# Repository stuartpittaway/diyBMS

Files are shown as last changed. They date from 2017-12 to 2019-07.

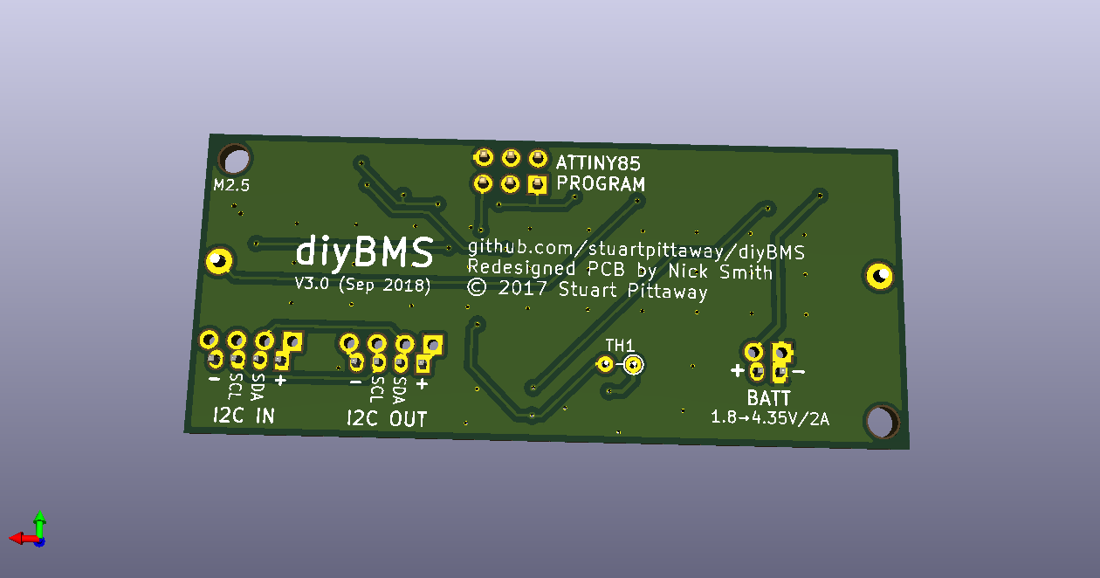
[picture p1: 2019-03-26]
BMS-Cell-Module-Circuit/PCB-back.png

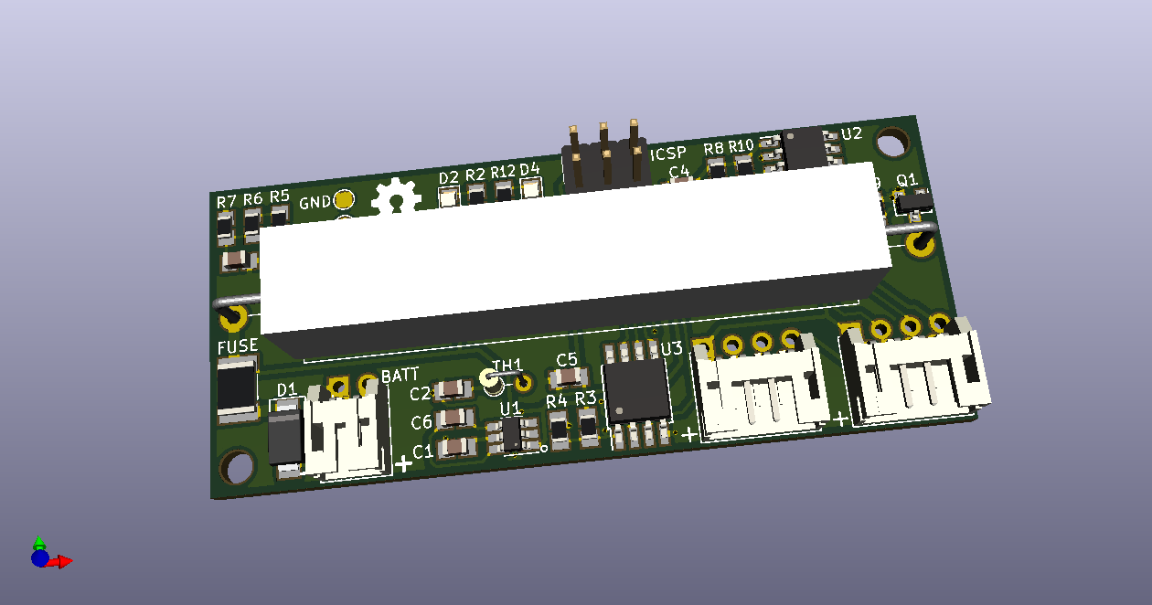
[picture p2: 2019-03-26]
BMS-Cell-Module-Circuit/PCB-3D.png

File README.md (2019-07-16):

# diyBMS
Do it yourself battery management system to Lithium ion battery packs/cells

More discussion
https://community.openenergymonitor.org/t/diy-lithium-battery-balancer-and-monitoring-bms/5594/10

** PLEASE NOTE THIS DESIGN HAS BEEN REPLACED WITH VERSION 4 **

https://github.com/stuartpittaway/diyBMSv4

# YouTube

https://www.youtube.com/watch?v=-CusvENqC4I&t=12s

Some Youtube videos on the BMS building and testing can be found at
https://www.youtube.com/playlist?list=PLiYbY8lzAN-2qB9rR0Sc7Z7sUrsgYzsiV

# Problem

A DIY Powerwall is the DIY construction of a pack of battery cells to create an energy store which can be used via inverters to power electrical items in the home. Generally cells are salvaged/second hand, and typically use Lithium 18650 cells.

Lithium batteries need to be kept at the same voltage level across a parallel pack. This is done by balancing each cell in the pack to raise or lower its voltage to match the others.

Existing balancing solutions are available in the market place, but at a relatively high cost compared to the cost of the battery bank, so this project is to design a low-cost, simple featured BMS/balancer.

A large number of people have utilised the commercial BATRIUM BMS system in their powerwall devices.

# My Situtation/Environment

UK based, but with only a small setup.  I have a 7s96p setup which i need to keep in balance.

# Existing Energy Usage

Through the monitoring of my home electric usage using the emonTX and emonSD solutions I typically use around 9kW/H per day (excluding electric car charging). Apart from odd spikes, load it generally less than 500W for the majority of the day/night.

# The Plan

Install a DIY powerwall with the ability to supply a 1000W load to cover all regular home usage (excluding spikes which the grid will handle).

A grid tied inverter would be required to convert the battery DC into mains level AC.

A controllable charger would be required to charge the battery during the day (or at cheap energy times from the grid). Ideally the charger should be able to match the generation of export from the solar array(s) to prevent import.

It may be possible to combine both charger and inverter into a single unit (so called hybrid units)

For obvious reasons, safety is critical, so care must be taken to ensure components are installed and certified as needed, along with the correct specification for cables, breakers and fuses etc.

Why am I doing this? For fun :slight_smile: I really must get out more!

# WARNING

Just a reminder that this is a DIY product/solution so don’t use this for safety critical systems or in any situation where there could be a risk to life.  There is no warranty, it may not work as expected or at all.

# Parameters

I’m working to the the following design parameters, which are taken from research into the area (what most others are doing!)

Assumption that second hand 18650 cells are made into “packs” containing tens or hundreds of cells in parallel.
Voltage of 18650 cell between 3.0V (empty) and 4.2V (full)
48V DC battery pack - running 14 packs/cells in series (aka 14S) this gives between 42V and 58.8V DC
Battery expected to output (1000W) so produce up to 25A current (depending on battery voltage)
Charger and inverter would be commercial products (not DIY) to comply with necessary approvals

# BMS Design

Building upon my existing skill set and knowledge, and also building something that others can contribute to using regular standard libraries and off the shelf components.

* Design a hub and spoke arrangement, for a central controller and individual cell monitoring nodes on each pack (so 14 in my case)
* Use Arduino based libraries and tools (possible move to platform.io) **
* Use esp8266-12e as the controller - to take advantage of built in WIFI for monitoring/alerting and CPU/RAM performance
* Use AVR ATTINY85 for each node
* Ensure each cell voltage is isolated from other cells and that ground voltage is isolated
* Isolated communications between controller and node is needed
* Put everything on GITHUB
* Document it!

** There are better more capable CPUs than the 8-bit Arduino however they lack user friendliness and the community to support and nuture the development of code

# Bill Of Materials

NOTE SIZES OF COMPNENTS SHOULD BE 0805 SIZED FOR THE SMALLER PCB VARIANT!

See BMS_Cell_Module_BOM.html for details

Links to main components
ATTINY85V-10SU
http://uk.farnell.com/atmel/attiny85v-10su/mcu-8bit-attiny-10mhz-soic-8/dp/1455166

REG710NA-3.3
http://uk.farnell.com/texas-instruments/reg710na-3-3-250/charge-pump-regulator-buck-boost/dp/1535743

Analog Devices ADUM1250ARZ
http://uk.farnell.com/analog-devices/adum1250arz-rl7/digital-isolator-4-ch-1mbps-nsoic/dp/2758723

SI2312BDS-T1-E3 MOSFET Transistor, N Channel, 3.9 A, 20 V, 0.025 ohm, 4.5 V, 850 mV
http://uk.farnell.com/vishay/si2312bds-t1-e3/mosfet-n-ch-20v-3-9a-sot-23-3/dp/2396085

B57891M0103K000 Thermistor, NTC, 10 kohm, B57891M Series, 3950 K, Through Hole
http://uk.farnell.com/epcos/b57891m0103k000/thermistor-ntc-radial-leaded/dp/2285471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

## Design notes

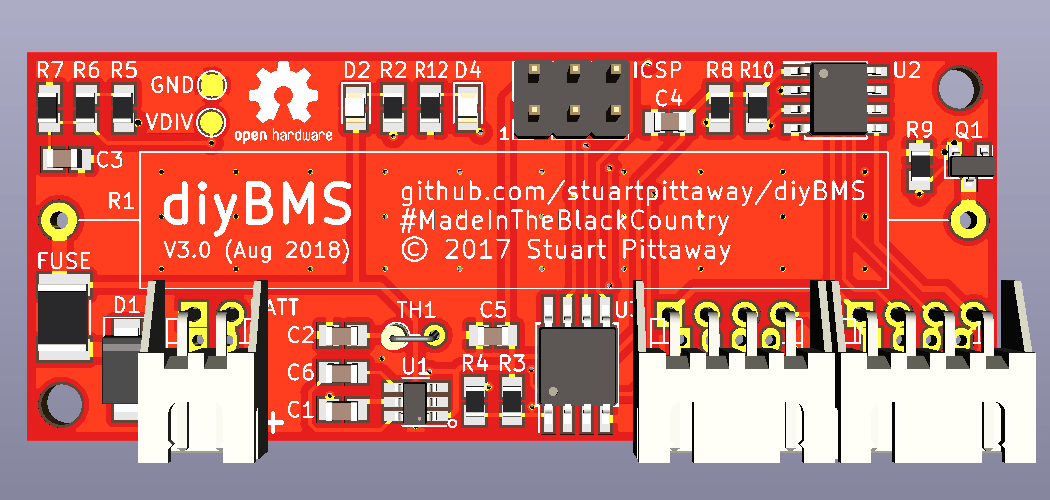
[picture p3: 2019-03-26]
BMS-Cell-Module-Circuit/PCB-front-XH.png

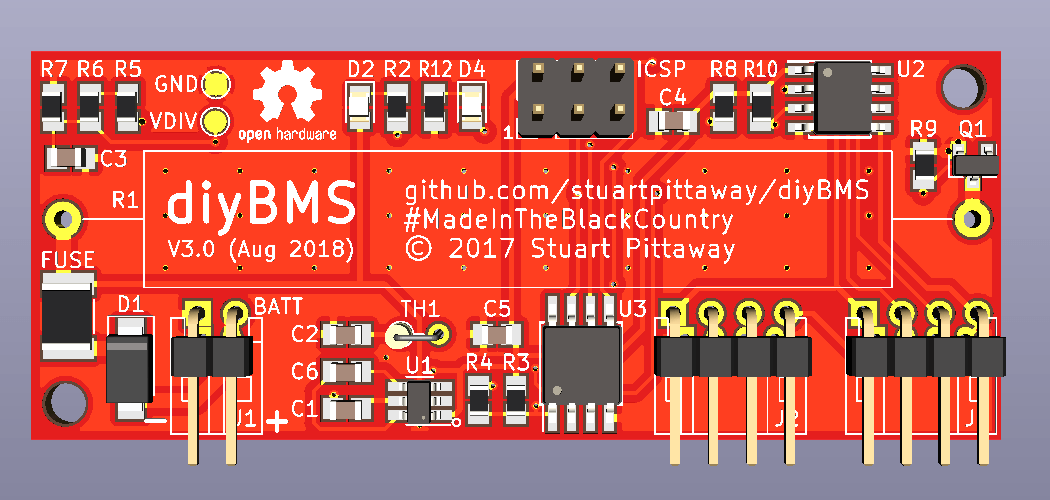
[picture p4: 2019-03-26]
BMS-Cell-Module-Circuit/PCB-front-pins.png

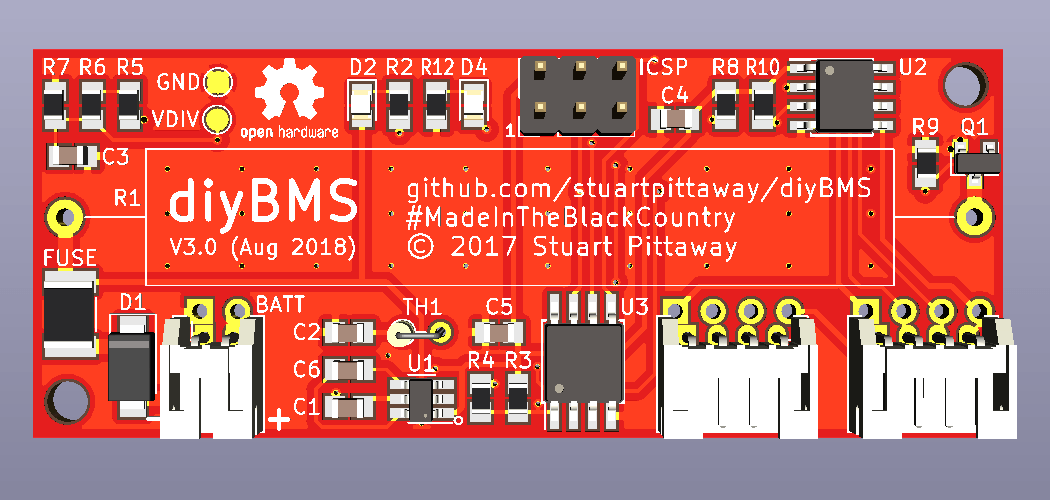
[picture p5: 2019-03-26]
BMS-Cell-Module-Circuit/PCB-front-PH.png

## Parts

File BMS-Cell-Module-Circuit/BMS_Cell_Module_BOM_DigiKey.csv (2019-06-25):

Manufacturer Part Number | Manufacturer | Digi-Key Part Number | Customer Reference | Reference Designator | Packaging | Part Status | Quantity | Unit Price | Extended Price | Quantity Available | Mfg Std Lead Time | Description | RoHS Status | Lead Free Status | REACH Status | US Tariff Status
CL21B225KPFNNNE | Samsung Electro-Mechanics | 1276-1188-1-ND |  | C1,C2 | Cut Tape (CT) | Active | 2 | 0.21000 | AU$0.42 | 235036 | Not Available | CAP CER 2.2UF 10V X7R 0805 | RoHS Compliant | Lead free | REACH Unaffected | Tariff Eligible
CL21B104MBCNNNC | Samsung Electro-Mechanics | 1276-2450-1-ND |  | C3,C4,C5 | Cut Tape (CT) | Active | 3 | 0.15000 | AU$0.45 | 952896 | Not Available | CAP CER 0.1UF 50V X7R 0805 | RoHS Compliant | Lead free | REACH Unaffected
CL21B224KBFNNNG | Samsung Electro-Mechanics | 1276-6478-1-ND |  | C6 | Cut Tape (CT) | Active | 1 | 0.15000 | AU$0.15 | 144430 | Not Available | CAP CER 0.22UF 50V X7R 0805 | RoHS Compliant | Lead free | REACH Unaffected | Tariff Eligible
SS34L RVG | Taiwan Semiconductor Corporation | SS34LRVGCT-ND |  | D1 | Cut Tape (CT) | Active | 1 | 0.62000 | AU$0.62 | 8209 | 14 Weeks | DIODE SCHOTTKY 40V 3A SUB SMA | RoHS Compliant | Lead free | Not Available | Tariff Eligible
150080VS75000 | Wurth Electronics Inc. | 732-4986-1-ND |  | D4 | Cut Tape (CT) | Active | 1 | 0.26000 | AU$0.26 | 66003 | 13 Weeks | LED GREEN CLEAR 0805 SMD | RoHS Compliant | Lead free | REACH Unaffected | Tariff Eligible
150080BS75000 | Wurth Electronics Inc. | 732-4982-1-ND |  | D2 | Cut Tape (CT) | Active | 1 | 0.26000 | AU$0.26 | 28862 | 13 Weeks | LED BLUE CLEAR 0805 SMD | RoHS Compliant | Lead free | REACH Unaffected | Tariff Eligible
0ZCG0075FF2C | Bel Fuse Inc. | 507-1763-1-ND |  | F1 | Cut Tape (CT) | Active | 1 | 0.19000 | AU$0.19 | 349464 | 18 Weeks | PTC RESET FUSE 16V 750MA 1812 | RoHS Compliant | Lead free | REACH Unaffected
PH2-06-UA | Adam Tech | 2057-PH2-06-UA-ND |  | ISP1 | Bag | Active | 1 | 0.16000 | AU$0.16 | 2904 | 6 Weeks | PIN HEADER 6P 2.54MM PITCH PLUG | RoHS Compliant | Lead free | Not Available
S4B-PH-K-S(LF)(SN) | JST Sales America Inc. | 455-1721-ND |  | J2,J3 | Bulk | Active | 2 | 0.32000 | AU$0.64 | 328980 | 16 Weeks | CONN HEADER R/A 4POS 2MM | RoHS Compliant | Lead free | Not Available
S2B-PH-K-S(LF)(SN) | JST Sales America Inc. | 455-1719-ND |  | J1 | Bulk | Active | 1 | 0.25000 | AU$0.25 | 147801 | 20 Weeks | CONN HEADER R/A 2POS 2MM | RoHS Compliant | Lead free | Not Available
SI2312BDS-T1-E3 | Vishay Siliconix | SI2312BDS-T1-E3CT-ND |  | Q1 | Cut Tape (CT) | Active | 1 | 0.78000 | AU$0.78 | 124182 | 91 Weeks | MOSFET N-CH 20V 3.9A SOT23-3 | RoHS Compliant | Lead free | Not Available | Tariff Eligible
SQP10AJB-2R0 | Yageo | 2.0W-10-ND |  | R1 | Tray | Active | 1 | 1.19000 | AU$1.19 | 5587 | 14 Weeks | RES 2 OHM 10W 5% AXIAL | RoHS Compliant | Lead free | REACH Unaffected | Tariff Eligible
CRGCQ0805J4K7 | TE Connectivity Passive Product | A130138CT-ND |  | R2,R8,R10,R12 | Cut Tape (CT) | Active | 4 | 0.15000 | AU$0.60 | 86691 | 28 Weeks | CRGCQ 0805 4K7 5% | RoHS Compliant | Lead free | Not Available
RC0805FR-0720KL | Yageo | 311-20.0KCRCT-ND |  | R3 | Cut Tape (CT) | Active | 1 | 0.15000 | AU$0.15 | 4953656 | 16 Weeks | RES SMD 20K OHM 1% 1/8W 0805 | RoHS Compliant | Lead free | REACH Unaffected | Tariff Eligible
RMCF0805JT10K0 | Stackpole Electronics Inc | RMCF0805JT10K0CT-ND |  | R4 | Cut Tape (CT) | Active | 1 | 0.15000 | AU$0.15 | 553885 | 17 Weeks | RES 10K OHM 5% 1/8W 0805 | RoHS Compliant | Lead free | REACH Unaffected | Tariff Eligible
RC0805JR-07510KL | Yageo | 311-510KARCT-ND |  | R6 | Cut Tape (CT) | Active | 1 | 0.15000 | AU$0.15 | 65727 | 16 Weeks | RES SMD 510K OHM 5% 1/8W 0805 | RoHS Compliant | Lead free | REACH Unaffected | Tariff Eligible
RC0805JR-07680KL | Yageo | 311-680KARCT-ND |  | R7 | Cut Tape (CT) | Active | 1 | 0.15000 | AU$0.15 | 122071 | 16 Weeks | RES SMD 680K OHM 5% 1/8W 0805 | RoHS Compliant | Lead free | REACH Unaffected | Tariff Eligible
CRGCQ0805F47K | TE Connectivity Passive Product | A129769CT-ND |  | R9 | Cut Tape (CT) | Active | 1 | 0.15000 | AU$0.15 | 67042 | 28 Weeks | CRGCQ 0805 47K 1% | RoHS Compliant | Lead free | Not Available
B57891M0103K000 | EPCOS (TDK) | 495-75622-ND |  | TH1 | Bulk | Active | 1 | 1.44000 | AU$1.44 | 1269 | 16 Weeks | THERMISTOR NTC 10KOHM 3950K DISC | RoHS Compliant | Lead free | REACH Unaffected
REG710NA-3.3/3K | Texas Instruments | 296-39168-1-ND |  | U1 | Cut Tape (CT) | Active | 1 | 1.88000 | AU$1.88 | 30858 | 8 Weeks | IC REG CHARGE PUMP 3.3V SOT23 | RoHS Compliant | Lead free | REACH Unaffected | Tariff Eligible
ATTINY85V-10SU | Microchip Technology | ATTINY85V-10SU-ND |  | U3 | Tube | Active | 1 | 1.70000 | AU$1.70 | 965 | 4 Weeks | IC MCU 8BIT 8KB FLASH 8SOIC | RoHS Compliant | Lead free | REACH Unaffected
ADUM1250ARZ-RL7 | Analog Devices Inc. | ADUM1250ARZ-RL7CT-ND |  | U2 | Cut Tape (CT) | Active | 1 | 8.89000 | AU$8.89 | 12306 | 21 Weeks | DGTL ISO 2.5KV 2CH I2C 8SOIC | RoHS Compliant | Lead free | REACH Unaffected

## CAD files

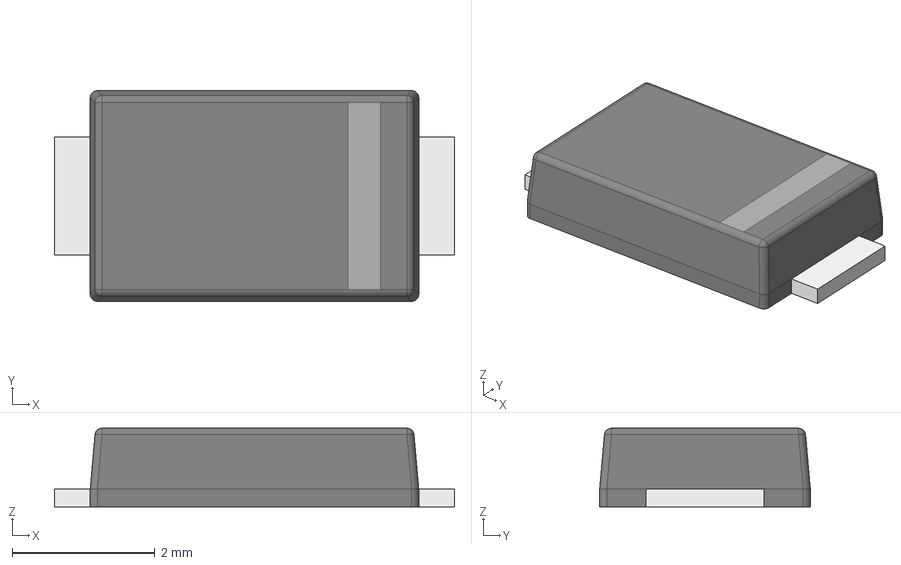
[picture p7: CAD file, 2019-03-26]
BMS-Cell-Module-Circuit/DO-221AC.stp
5.60 x 2.95 x 1.10 mm

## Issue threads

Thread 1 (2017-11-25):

ATTINY85 pcb footprint is too small

stuartpittaway, 2017-11-25:
Current footprint on PCB is soic-8_3.9x4.9mm_pitch1.27mm

This should be a SOIC-8 WIDE

stuartpittaway, 2017-11-25:
Can be made to work by squashing the legs into the chip body - but needs changing for next version

stuartpittaway, 2017-12-02:
Fixed in latest PCB layout

Closed 2017-12-02.

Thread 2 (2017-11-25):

ADUM1251 footprint slightly too wide

stuartpittaway, 2017-11-25:
ADUM1251 footprint is SOIC-8-N which appears too wide but will just make electrical contact as it is (just!)

chickey, 2017-11-25:
I’ll have to check which I ordered 😨

stuartpittaway, 2017-11-25:
If you get the chip dead centre there is enough contact for the solder, but its tight!

stuartpittaway, 2017-12-02:
Fixed in latest PCB layout

Closed 2017-12-02.

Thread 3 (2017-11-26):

PCB works - almost!

stuartpittaway, 2017-11-26:
I've put together version 1 of the PCB and it appears to work okay - but not as reliable as my breadboard version.

The i2c traffic works for several requests then appears to skip a few requests and then works again for a few more etc.  The breadboard version is rock solid.

The ADUM1250 chip took a bit of a bashing when soldering, so this may be the weak point - although it does work intermittently.

chickey, 2017-11-26:
Hopefully won't take too long for my boards and surface mount attiny's to
arrive.  Thinking about it i could breadboard one up quite easily minus the
ADUM with it being surface mount.

On 26 November 2017 at 10:44, Stuart Pittaway <notifications@github.com>
wrote:

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

stuartpittaway, 2017-11-26:
I used some SOIC adapter boards which work quite well.

stuartpittaway, 2017-11-26:
Panic over, nothing wrong with the board or ADUM chip - I was using an MCP1702 regulator instead of the 1703A but only feeding the board with 3.3V from supply which caused it to brown out every now and again.

I also think I need to remove the RED led circuit components as the board is pulling a few extra mA current with that resistor network always connected.

stuartpittaway, 2017-11-27:
Second panic over, looks like I killed the ATTINY chip during soldering or testing - the ADC on Pin 2 appeared to work, but the reading would slowly drop in value over a few minutes.

Removed and replaced the ATTINY and works fine now.

Closed 2017-11-27.

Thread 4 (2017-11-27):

Change capacitors to 1206 SMD sizes

stuartpittaway, 2017-11-27:
Change capacitors to 1206 SMD sizes instead of 1210 as these are easier to find/buy in 0.1 and 1uF sizes.

chickey, 2017-11-27:
Ah thanks i'll see what i've got in, i have some but i think they are 0603, might just order some more from farnell.

stuartpittaway, 2017-11-27:
Ordered a bunch from good old AliExpress but thats going to take a few weeks to turn up!

stuartpittaway, 2017-12-02:
Fixed on latest version of PCB

Closed 2017-12-02.

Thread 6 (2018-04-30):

Is resistor R2 too low?

stuartpittaway, 2018-04-30:
Original design had R2 as 47 ohm

Using..
https://www.digikey.co.uk/en/resources/conversion-calculators/conversion-calculator-led-series-resistor

4.2V supply, 3.3V forward voltage (blue LED) and 20mA current gives 45ohm resistor - so the 47 is a logical choice.

Note that R2 also adds to the balance load on the cells in addition to the load resistor.

What do others think?

CuriousTimo, 2018-04-30:
Hi Stuart,

Adam Welch explains it well in his YouTube video
https://youtu.be/ETw4SNH7SXI?t=605
His video was what decided to switch to a 510R resistor.

Cheers,

Timo

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

chickey, 2018-04-30:
With 510ohm, wouldn't that give just over 2ma which seems really low.

AdamWelchUK, 2018-05-01:
Hello all.  I guess this is mentioned because of my mistake.  I forgot to factor in the voltage drop of the LED into my calculation and suggested R2 was too low in my video.  So firstly Stuart, sorry about that, I hope you will forgive me.

As you know I've put a 510ohm in for R2, which as you say Colin gives about 2mA.  Now, although that original decision is based on incorrect maths I'm going to stick with 510 ohm.  I've attached two images which I took with fixed settings on my camera a few seconds apart.  One is running at 2mA the other 20mA.  It's hard to reproduce light levels on camera, but it should give you a rough idea.

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

To add to the discussion I'll argue that the value of R2 will entirely depend on each users individual situation.  A system placed in a dim environment rather than a sunny one is one factor, but the amount of time the LED is likely to be lit is another. My LEDs were very cheap and I'd rather not have to replace them, running them at a low current should help that considerably.  I've also swapped the suggested blue LED for red - with a lower forward voltage.  Red makes more sense to me as an indicator to suggest something is wrong (high) or we're burning off the energy.
Now I'll also argue that R2 may be chosen with consideration of R1.  If you are aiming for a discharge current of 200mA for example (say with a 20ohm R1) then an additional 20mA is an additional 10%, but if you are going for a ~1amp discharge current (eg. R1 is 4.3 ohm), then 20mA extra is almost nothing.

Cheers

stuartpittaway, 2018-06-11:
Thanks for the post @AdamWelchUK closing this issue now as you explain the reasons why very well :-)

Closed 2018-06-11.

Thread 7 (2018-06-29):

documentation

tvixen, 2018-06-29:
Hi Stuart
Thanks for this great project.....
Would it be possible for you to write some documentation.

How it shall work, incl. status of the green led blink ... what to do on the webpage, and the functions in here. (manual calibration aso... )

Thanks in advance
Tim

chickey, 2018-06-29:
https://www.youtube.com/playlist?list=PLiYbY8lzAN-2qB9rR0Sc7Z7sUrsgYzsiV

Hi Tim,  I did a short video series on the BMS.

Col

tvixen, 2018-06-29:
ahh super i'll have a look. Thanks mate.

Closed 2019-03-26.

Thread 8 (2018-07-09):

The direction of ALUM1250

tvixen, 2018-07-09:
Hi Stuard
I have had a closer look at your diagram, and it seems to me that you have turned the ic2(ALUM1250) 180 degrees around. The datasheet says that the pins to the I2C BUS should be 8,7,6,5 But you have used 1,2,3,4..... what was the reason to do that ?

 (http://www.analog.com/media/en/technical-documentation/data-sheets/ADUM1250_1251.pdf
  ....  page 11)

Br Tim

stuartpittaway, 2018-07-09:
Hi Tim, in the situation of this circuit where both sides of the i2c bus are communicated with processors which are i2c compatible (not compliant) it doesn't really matter which way around the comms is.

The spec sheet mentions that "Side 2 of the ADuM1250/ADuM1251 is I2C compliant, whereas Side 1 is only I2C compatible" which would be important if side 2 needed to be i2c compliant - but in this scenario it doesn't.

tvixen, 2018-07-09:
Hmm, well I still think this could be a issue, as you can pull 10 times more power from side2 (with all the slaves) + the 2K2 on side1 is is way to high.  As I read the specs, they should be 1K when using 100n as C4  ;o)
Any way, you have done a great job, but I think I will give it a try, turning it the right way, in my next print layout.

Br Tim

stuartpittaway, 2018-07-09:
That's the beauty of GitHub, happy to accept a pull request with the fixes/changes. Thanks

tvixen, 2018-07-10:
Hi Stuard
I would be glad to, but im using Eagle and your using Kidcad.... I think this will be a miss match of different files, and confusion for the users.

Br Tim

stuartpittaway, 2018-07-10:
Agreed, so you are starting a new project then?

tvixen, 2018-07-10:
Well the project are already 99% done. and I'm doing the final work tonight. Then order a new set of PCB's, and then test them. So I don't know if I'm gonna write it on github.... seems as a good idea, but I have never done it before so I don't really know how to start :o/

Br Tim

tvixen, 2018-07-11:
Now you've got me started :D ...
https://github.com/tvixen/diy-BMS-with-Arduino-Nano

stuartpittaway, 2018-07-11:
Just a comment on the 2k2 resistor on the i2c bus - the spec does mention the lowest resistor should be 1k, however as there is only 1 item on this side of the i2c bus (the ATTINY chip) then the capacitance of the bus will be fine.  The resistor on the other side of the bus should be 1k to the NodeMCU.

No reason not to make it 1k, but it does work as it is.

tvixen, 2018-07-11:
I don't think the capacitance of the bus on the ATTiny chip side, will be the biggest problem, and if we keep the wires short, probably not at problem on the slave side, but because you have turned the IC 180 degrees, I think the power can turn out to be a issue in combination with the pullup's to I2C compliant level.
I have made the new ones with side2 to the common I2C bus. Let's see if it makes the bus more stabile.

Closed 2019-03-26.

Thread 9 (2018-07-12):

New PCB

tvixen, 2018-07-12:
Hi Stuart

I made a new PCB for you. You can have a look and if its ok, approve it.
This one is made with THT components, as many people don't have SMD in the drawer

Br Tim

tvixen, 2018-07-12:
And here goes the files:
[DIY BMSP Ver 3.0 brd .pdf](https://github.com/stuartpittaway/diyBMS/files/2188281/DIY.BMSP.Ver.3.0.brd.pdf)
[DIY BMSP Ver 3.0 sch .pdf](https://github.com/stuartpittaway/diyBMS/files/2188282/DIY.BMSP.Ver.3.0.sch.pdf)

brunkj, 2018-07-12:
nice!  What is the physical dimensions of the board?

tvixen, 2018-07-12:
78mm x 48mm

stuartpittaway, 2018-07-12:
Nice work!  Do you need the capacitors on the inputs/outputs of the ADUM1250 module ?

tvixen, 2018-07-12:
I would say, it depends of the length on side 2. But you will have a nicer risetime, and that might eliminate some i2c errors.

Closed 2019-03-04.

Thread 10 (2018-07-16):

ESP code conver to Arduino Uno code

Rorschac, 2018-07-16:
Hi, I want to convert "ESP test" code  to arduino uno code. I have removed some code lines specified for ESP8266, and I compiled with any problem for Arduino uno.  Now, I have tested this code that i send "X" from serial interface. I see the message on I2C, but attiny85 did not response.  I added scope screen and lines that i removed from code.

```
extern "C"
{
  #include "user_interface.h"
}

os_timer_t myTimer;

//  os_timer_setfn(&myTimer, timerCallback, NULL);
//  os_timer_arm(&myTimer, 1000, true);
```
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

tvixen, 2018-07-16:
Hi there
If it helps, you can have a look at my code.
I converted it into a Arduino Nano :+1:   https://github.com/tvixen/diy-BMS-with-Arduino-Nano

Br Tim

chickey, 2018-07-17:
Have you burnt the fuses on the attiny85?

Rorschac, 2018-07-17:
Yes. I designed my own board with altium based on orginal schematic and component for product PCB at home. I want to share this design if I can run it. I bootloaded orginal code in fourteen attiny85. Just I changed ESP code for load uno or mega. I can send message with uno on I2C but no response attiny85 board.

chickey, 2018-07-17:
Ok asking as I had no luck initially and had to increase the stretch clock from 1000 to 2500 as memory serves as I couldn’t get any communication either but I hadn’t set the fuses so the speed etc was incorrect and the stretchclock increase kind of masked the issue.

tvixen, 2018-07-17:
You can use Stuart's slave software, and then try mine for your master (UNO) This should work.

Rorschac, 2018-07-17:
I used your code but no difference. Uno sends but attiny85 not talk. I see the signal at the output of ADUM but attiny is not talk.

Merdeka, 2018-07-17:
Haven't tested it but could it be an issue with the default i2c bus speed? 100khz vs 400kHz.

Cheers,
Timo

Rorschac, 2018-07-17:
I found a ESP8266 and used the orginal code, original bus speed. It doesn't work too. Attiny85 doesn't reponse again. I controlled everything on pcb. It seems normal. I don't know why not running it?

tvixen, 2018-07-17:
Do you see the green diode blink on the Cell_module. If not, check your programming of the ATTiny85.

tvixen, 2018-07-17:
If you use Uno, you don't have to use Optiboot. As it's only Nano having a problem with the watchdog.

tvixen, 2018-07-17:
Try ONLY to connect one module to the bus. When this is working, add another. aso aso.

chickey, 2018-07-17:
Also try the clock stretch change

Rorschac, 2018-07-17:
Led is not blinking. But I saw a video on youtube, diyBMS tutorial it haven't blinking too. Already I'm working with only one cell.  Also I controlled reset pin voltage, it's almost 2V.

https://www.youtube.com/watch?v=ZahB-86zzfQ

chickey, 2018-07-17:
https://youtu.be/CbuOteAcv04

Rorschac, 2018-07-17:
Thanks, I have watched video now.  I guess, your github code have all changes from your video. I will try now.

Rorschac, 2018-07-17:
Did you added 2.2K pull-up resistors to esp I2C wire, except modul?

tvixen, 2018-07-17:
Yes this is very important to do. If not, there's no 'power' to feed the bus.

Rorschac, 2018-07-18:
I loaded Colin's codes. SCK does not seem normal, does it? It's a bit short.

Scope1-SCK
Scope2-SDA

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

chickey, 2018-07-18:
Module code should be identical and I backed out the stretch clock changes in the controller code.  I more put the video to show the issues I had as I hadn’t done the fuses etc

Rorschac, 2018-07-18:
Is it possible to communicate with the scope as it looks? As a result, everybody have worked. Should I search the fault somewhere else? I know I'm starting to get boring, I'm sorry for that but I need help.

Rorschac, 2018-07-18:
There is a warning in the code. Could the factory have set for external crystal?
Because the module does not work even in the simplest code like led blink.

`If you burn incorrect fuses to ATTINY85 you may need to connect a crystal over the pins to make it work again!`

Rorschac, 2018-07-18:
I found something like this. I hope this is the problem.
[](http://www.instructables.com/id/Simple-and-cheap-Fuse-Doctor-for-Attiny)

Rorschac, 2018-07-19:
I have a good and bad news for you. The good news is that the problem is solved, the bad news is that I think the bootloading code is loading. I hit the upload button and the problem is solved. And Colin, your arrangements are wonderful. I thank you all very much.

Closed 2019-03-04.

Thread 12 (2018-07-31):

Not compiling under Linux

delboy711, 2018-07-31:
While waiting for my diyBMS boards to arrive from China I checked to make sure the code compiled.

Under Linux I found Arduino-ESP8266-BMS-Controller.ino does not compile because  line 39
#include "softap.h" has incorrect capitalization.
Line 4 in SoftAP.cpp has the same problem.

Looking forward to getting to grips with this project. I intend to try running it on an ESP32 if possible since I would like to incorporate the BMS function on the same controller as battery charge/discharge rate control, and need the extra pins of an ESP32.

stuartpittaway, 2018-09-02:
Fixed, thanks.

Closed 2018-09-02.

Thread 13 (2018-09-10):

Qi Charger for DC/DC Isolation and Dump Load?

jamestutton, 2018-09-10:
Hi have an idea and wanted to float it here as know there a few makers using this project who might be willing to test it out and don't have time nor facilities to test it myself right now.

So as you can see from the topic the idea is a Qi charger as far as my understanding goes Qi provides ~5W of DC/DC isloation. So the concept is rather than (or as well as) a DUMP resistor why not have a QI Charger and receiver to bypass power to the next pack.  In its simplest form this could be:

**PACK 1:**
MOSFET -> 5V boost circuit to USB port-> Qi plate
_()()()()()()()()()()()()()()()()()()()()()()()()()()()()()()  **Isolation** _
**PACK2:**
Qi Receiver -> TP4056 Battery -> Batteries

Am I onto something or is there something fundamental I'm missing with this concept. Know the losses would be high but a load resistor is 100% loss so figure even high losses could still be worthwhile.
Aware there are dedicated Isolated DC/DC convertors but most seem to be low power (<2W) and the ICs seem to be more expensive per W that QI.

stuartpittaway, 2018-09-26:
This might be possible, but isn't really part of this project.

Closed 2018-09-26.

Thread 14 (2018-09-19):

BOM updated

ArchGalileu, 2018-09-19:
Hello

Which BOM? from README or from wiki?

Does it make difference from Colin Hickey?

Any chances to have a list from farnell?

I'm new to this, more or less, so to not mistake better to ask ;)

Best regards
ArchGalileu

stuartpittaway, 2018-09-19:
Hi ArchGalileu, the circuit in Colin's branch is the same as this one - its only the code thats different.

I've not got a farnell list I'm afraid - but most of the components are available from most suppliers.  I got mine all through AliExpress for cost reasons.

KrX3D, 2018-09-26:
hello,
i bought mine from readme, where is the wiki and whats the difference?

ArchGalileu, 2018-09-26:
My mistake... from README is correct ;)

fjgaston, 2019-02-20:
Hi Stuart,
I'm ordering parts at the moment, as I'm going to build your BMS for my battery.
I noticed the Drain Resistor is noted for 50 Watts it seems to be huge, did you mean 5 Watts.
From my calculations with 4.2 Volts and a 3R3 resistor the power would be 5.35 Watts so I guess a 7W should be enough ?
For the ADUM1250, do you think the MAX14933 could be a good less expensive substitute ?

Zbysekz, 2019-02-20:
7 Watts will go very very hot... i bought these on aliexpress. https://imguh.com/image/oIHBh

Zbysekz, 2019-02-20:
And i have used ISO1540DR, it is more available in EU and the price is also good. I will post complete schematics etc.. when it will be finished

fjgaston, 2019-02-20:
I think I will go for a 10 Ohms resistor instead, the maximum will be 1.764 Watts so I guess a 10 Watts wirewound resistor like this one [https://fr.farnell.com/multicomp/mcprw0awjw100b00/wirewound-resistor-10-ohm-10w/dp/1737549](https://fr.farnell.com/multicomp/mcprw0awjw100b00/wirewound-resistor-10-ohm-10w/dp/1737549) should be more than enough.
The BOM in the readme says components cost is around £5.50 but on farnell a 3R3 50 Watts resistor is more than 6£ :-/
Anyway the 10 ohms resistor will be enough for the moment for small balancing.
I ordered ADUM1250s on Aliexpress (x5 times cheaper this is crazy) but I'll also order a MAX14933 to test the difference (it's 1.96€ on farnell vvs 5.47€ for the ADUM1250 and 4.53 for the ISO1540) there is also the SI8600AB taht is 2.94€ I wonder if they would be all be compatible?

stuartpittaway, 2019-02-20:
> 7 Watts will go very very hot...

Agreed it will get hot!

stuartpittaway, 2019-02-20:
> The BOM in the readme says components cost is around £5.50 but on farnell a 3R3 50 Watts resistor is more than 6£ :-/

Yes although I brought a lot of items from AliExpress - take a look at...

https://www.aliexpress.com/item/Novel-Auto-Car-Vehicle-4Pcs-Professional-50W-Load-Resistor-6ohm-Fix-LED-Bulb-Fast-Hyper-Flash/32907694269.html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,searchweb201602_8_10065_10068_10130_10547_319_317_10548_10696_10192_10190_453_10084_454_10083_10618_10307_10820_10301_10821_10303_537_536_10902_10059_10884_10887_321_322_10103,searchweb201603_57,ppcSwitch_0&algo_expid=00d20ee5-5890-4a57-ad6a-245f0c2d67bd-0&algo_pvid=00d20ee5-5890-4a57-ad6a-245f0c2d67bd&transAbTest=ae803_5

or search for "Novel Auto Car Vehicle 4Pcs Professional 50W Load Resistor 6ohm Fix LED Bulb Fast Hyper Flash Turn Signal Light Bulb"

$3 for 4x 50W resistors

fjgaston, 2019-02-20:
thank you for the infos, I just forked this project and building one now, I'll keep you updated :-)

Church1182, 2019-02-20:
I just ordered parts for mine and mixed Mouser and AliExpress parts with boards from www.allpcb.com. I'm sitting at a cost per board for 15 boards of $8 US. I'm sure that can be lower if you take the time to source all parts through AliExpress and eBay sites.

fjgaston, 2019-02-20:
sourcing parts takes so much time (and it's much less interesting than building or programming)

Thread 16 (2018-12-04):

Thermistor voltage divider in cold weather

stuartpittaway, 2018-12-04:
As per this video by Adam
https://www.youtube.com/watch?v=TvLTTbvqvj4

The voltage divider resistors for the temp sensor are too low - change the 10K to 20K to suit temp down to 0 degrees C

stuartpittaway, 2018-12-04:
Updated diagram and BOM

Closed 2018-12-04.

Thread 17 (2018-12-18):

DIY BMS Stencil for 3D printing

PapaStauth, 2018-12-18:
[DIY BMS Stencil.zip](https://github.com/stuartpittaway/diyBMS/files/2691789/DIY.BMS.Stencil.zip)
Stencil attached to screen the solder paste to your PCB.
From http://solder-stencil.me/
Using *.GM1 and *.GTS files
Using 0.25 mm layer height
Including a 1.2 mm stencil ledge for indexing

stuartpittaway, 2018-12-19:
Thanks for the stencil.  You can also order these via the PCB company like JLCPCB or ALLPCB

Closed 2018-12-19.

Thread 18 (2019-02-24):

why 3.3V for the ATTiny ?

fjgaston, 2019-02-24:
Hi, sorry if this question is not relevant, I'm just a beginner, why do you use a 3.3V buck/boost converter and not a 5V boost converter to power the ATTiny ?

stuartpittaway, 2019-02-24:
Hello, you could use a 5v boost converter however as we communicate with the esp8266 that needs 3.3v via the adum chip.

fjgaston, 2019-02-24:
I though the logic voltage on each side of the ADUM1250 was relative to the VDD, I though it could have 5V on one side and 3.3V on the other side

stuartpittaway, 2019-02-24:
Yes you are correct, I had dumb moment there!!

fjgaston, 2019-02-24:
Yet I don't think it is dumb cause while you were in the prototyping process, I think you had to test the module before putting the isolator so it made more sense to have the same voltage as the ESP.

Closed 2019-03-26.

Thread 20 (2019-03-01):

J1, C6 and C1 are very close on the PCB (v2.1)

fjgaston, 2019-03-01:
Hi,
I just started oldering my first PCB and I noticed that C6 and C1 are bigger than the footprint (I ordered a 1210 smt version as mentioned in the readme) so it's not easy to solder J1, C6 and C1 without having them touching each others.
Adam Welch also mentioned it in his video [https://youtu.be/ETw4SNH7SXI](https://youtu.be/ETw4SNH7SXI)

 From I see there sould be enough room on the PCB to put C6 and C1 lower.

stuartpittaway, 2019-03-04:
Hello, I can see that C6 and C1 are close together - I use solder paste so the capacitor sits on top of the pads.

You mention J1 - this should be easy to solder as its on the other side of the board?

fjgaston, 2019-03-04:
I mentioned J1 but in fact I wanted to mention the REG710-3.3
Maybe I should have ordered smaller capacitors.
Anyway I'll try to draw a gerber file and if I succeed, I'll send it to you if you want.

stuartpittaway, 2019-03-04:
Did you see the smaller PCB already in use? Its in the "small" branch.  This has probably already fixed the issues you have.

Zenkormalorvi, 2019-04-01:
Hi, I am also experiencing some issues with the capacitors being really close together and the 1210 size units extending to the extreme ends of both pads basically making it impossible to solder with an iron.  I ordered my boards on mar 7 2019 so it should have been updated from the previous user comments.  I appreciate everything you guys have done with this project. Thanks so much

fjgaston, 2019-04-01:
Did you use the smaller PCB or the standard?
I had also troubles with the first two boards I soldered, pin 6 of the REG710 was badly soldered and I had to de-solder C6 to re-solder it. It's funny that the same thing happened to me twice on the same pin of the same component. Maybe the pads could be a bit wider on the PCB? Maybe it works better with the soldering paste method but I don't have soldering paste.

aussiegwapo, 2019-04-01:
Did you use solderpast or solder the old fashion way with wire and iron.
Could even try hot fry pan to settle the solder evenly.

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

stuartpittaway, 2019-04-01:
Okay, I can see the confusion.  People are building the smaller PCB using the component list from the larger version.

All parts on the smaller pcb are 0805 sized, not 1210 like the older larger board.

I recently removed the larger board from github so hopefully this problem goes away for new starters.

fjgaston, 2019-04-01:
Soldered the old fashion way this the soldering iron, I don't feel comfortable with the solder paste.
Thank you fir the feedback Stuart and thank you for this incredible project.

stuartpittaway, 2019-04-09:
Yes you can hand solder 0805 - you will need tweezers or similar to hold the component.

Some times its easier to put a small blob of solder on each pad and then press the component onto the top and touch each pin/leg with the iron to remelt the solder pad.

Zenkormalorvi, 2019-04-09:
Yes you can solder all the components on the smaller pcb design including the 0805 size ones with a soldering iron. I just finished soldering mine a few days ago and it is working. I recommend putting solder on 1 pad only and then using tweezers to position the component. once the component is positioned correctly and soldered on 1 pin then continue soldering the other pins. also, flux is your friend.

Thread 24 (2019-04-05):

ATTiny acting weird

fjgaston, 2019-04-05:
Hi,
I just made my first module board and I started experimenting with it.
I burnt the bootloader and uploaded the code with the Arduino IDE and then I was able to read the voltage of the battery via I2C with my esp32 (I'm still waiting for my ESP8266).
Then the next day, I wasn't able to read the voltage and I wasn't even able to upload any program to the ATTiny "Yikes!  Invalid device signature".
I investigated what could be wrong, the reset pin is 2.1V, it should be enough. When I de-solder the ATTiny85 I'm able to burn the bootloader or upload programs so it seems like the problem is in the board.
When I power it, the green led blinks once then 2 seconds later the green led turns on and stays on.
I can't figure out what's wrong and the strange thing is that it was working very well yesterday.

stuartpittaway, 2019-04-06:
Hello, this could be many things, I'd suggest:

1. Check wiring on the ISP header and pins
2. Check for solder bridges between pins on the ATTINY
3. Check you run "burn bootloader" against the attiny with the correct settings (this burns the fuses)
4. Ensure you never select an external crystal on the Arduino menu

Closed 2019-04-06.

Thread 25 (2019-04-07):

PWM driven mosfet onstead of resistor (not an Issue)

uploader18, 2019-04-07:
Hi!

Since in my packs built from used 18650 there is no use for small balancing currents as they are not all same capacity, I was wondering if you were thinking about using mosfet as dummy load or even a flyback converter for regenerative balancing?

Regards Žiga

stuartpittaway, 2019-04-07:
Hi, I've no plans to move away from resistor based load balancing - it works for 18650 cells, what do you use?

uploader18, 2019-04-07:
For now I use flyback converter that boosts 4.2V to 48V. I am charging my packs with 80Amp and I need at least 10Amps of balancing current. My system is very simple...when cell reaches 4.1V it starts balancing with input current limit to primary side and no voltage regulation on secondary side(48V).

fjgaston, 2019-04-07:
I've seen somewhere a project where a DC/DC converter is used for balancing, I don't remember the website or the name.
Having the same capacity on every cell is important because your battery's capacity will be your smallest cell's capacity.
If your cells don't have the same capacity you can use more cells in parallel to better match the capacity.

uploader18, 2019-04-07:
I have packs 100p 14s but since there are mix cells with mixed capacity and degradation it is almost impossible to get them all equal, you can get close but once you have 200Ah packs and there is 20Ah difference you have a problem with unbalance. So it is easier for me ta make an active balancer. I would spend a lot of time measuring capacity of every pack and then add cells.

fjgaston, 2019-04-07:
just take some cells from the biggest pack and put them in the smallest pack

uploader18, 2019-04-07:
At fist i did just that, but i spot welded fuses on batteries and disassembling whole pack since i have 5x4 holders is a nightmare.

uploader18, 2019-04-07:
This guy made a nice balancer.
https://hackaday.io/project/20825-low-cost-non-dissipative-active-battery-balancer

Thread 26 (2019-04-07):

Temp calibration

hepike, 2019-04-07:
Hi,

After I calibrate manually the temperature on the modul site, then the voltage goes to zero. Without calibration it shows much higher value, so I need to calibrate somehow.

Thanks.

acidice333, 2021-01-27:
Did you ever solve this?  I had a similar problem that also I think resulted in that same behavior but I think I may have fixed it in my fork of the Controller.   I had a NaN issue with temperature conversion and it was causing problems

stuartpittaway, 2021-01-27:
It was so long ago I cannot remember! I've been working on v4 since.

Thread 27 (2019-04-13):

Confused

mikegleasonjr, 2019-04-13:
Hi, going through the README it is not obvious of the master branch is the smaller PCB variant. Since the smallpcb branch is several commits behind master, which is which?

Also, I heard that a contributor (Colin?) made several updates, are they incorporated here or his fork more up to date?

In short, there is no clear BOM and instructions. Or do I miss something?

stuartpittaway, 2019-04-13:
Hello, the current master branch is the correct one.  Colin did make some code changes, and they were merged in to the master branch recently.

mikegleasonjr, 2019-04-14:
Thanks will try to gather everything up to assemble your BMS and create a PR if needed for the docs!

Closed 2019-04-14.

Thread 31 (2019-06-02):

When was R5 removed?

Alpha-IT-Centre, 2019-06-02:
I had boards fabricated and they have in the top left R7, R6, R5. But on the kicad file it has no R5, which version was this removed in, the board I have has V3.0 (Sep 2018) on it.

stuartpittaway, 2019-06-02:
R5 can be replaced with a jumper wire across the two pins it was left over from a previous design

DavidBTB, 2019-06-20:
On the BMS cell module schematic off, R5 is 47k and part of the voltage divider. Is that wrong?

stuartpittaway, 2019-06-20:
The pdf is out of date.

Closed 2019-06-02.

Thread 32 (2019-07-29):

Access to the interface when no internet connexion

fjgaston, 2019-07-29:
Hi,
I can't connect to the interface when I have no internet.
I see it tries to access https://stuartpittaway.github.io/diyBMS/loader.js
It can be a problem mostly when having a mobile system (or being somewhere with unreliable internet)
Is there a way to easily solve this ?

stuartpittaway, 2019-07-29:
Hello, unfortunately not at this time.  It was designed this way so that the BMS is always using the latest web interface, however the downside is that an Internet connection is required.

The Version 4 DIYBMS doesn't have this issue as all the code is on the WeMOS.

A similar code change could be made on the V3, but I won't be doing this myself but happy to accept a pull request from others.

fjgaston, 2019-07-29:
thank you for the reply, I'll go for the v4 for my next build, it seems to have many other advantages.

acidice333, 2021-01-24:
i have made a fork with code updates to work offline.
https://github.com/acidice333/diyBMS

you will have to upload the file system once you've uploaded the new Controller code.
see https://github.com/earlephilhower/arduino-esp8266littlefs-plugin for details on doing that.

stuartpittaway, 2021-01-24:
Thanks for this, this is for version 3 of the diybms, which has been obsolete for a long time now, but thanks for taking the time to add new features.

Closed 2019-07-29.

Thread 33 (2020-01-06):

Missing R5 from BOM

jchengz, 2020-01-06:
https://github.com/stuartpittaway/diyBMS/blob/fbb3a6768bcf161922cc269b395a237fadc689d8/BMS-Cell-Module-Circuit/BMS_Cell_Module_BOM.html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

stuartpittaway, 2020-01-11:
I don't recommend diybms v3 for new builds - use the v4 instead

https://github.com/stuartpittaway/diyBMSv4

Closed 2020-01-11.

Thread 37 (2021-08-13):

Suggestion: make the 5.08mm terminal holes a tad bigger

SergioRius, 2021-08-13:
The holes for the relay terminals are the same as an others. These terminals being 5.08mm generally have bigger pins. I had to grind the pins on my terminals to fit.

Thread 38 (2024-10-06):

Victron Max Voltage (CVL) is gone after an update

TurboMOD, 2024-10-06:
Hi, in the past I had those options to Setup CVL, CCL and DCL for my Victron Multiplus. It was on the page diybms/victron settings or something like that. I dont find it anymore (maybe its gone after an update?), but it is still reducing the current to my battery because I had set the voltage (CVL) way to low in the past. Is there a way to change this?

stuartpittaway, 2024-10-06:
Those settings are on the charge discharge page.

Here you can set the maximum charge voltage and current charge curves.

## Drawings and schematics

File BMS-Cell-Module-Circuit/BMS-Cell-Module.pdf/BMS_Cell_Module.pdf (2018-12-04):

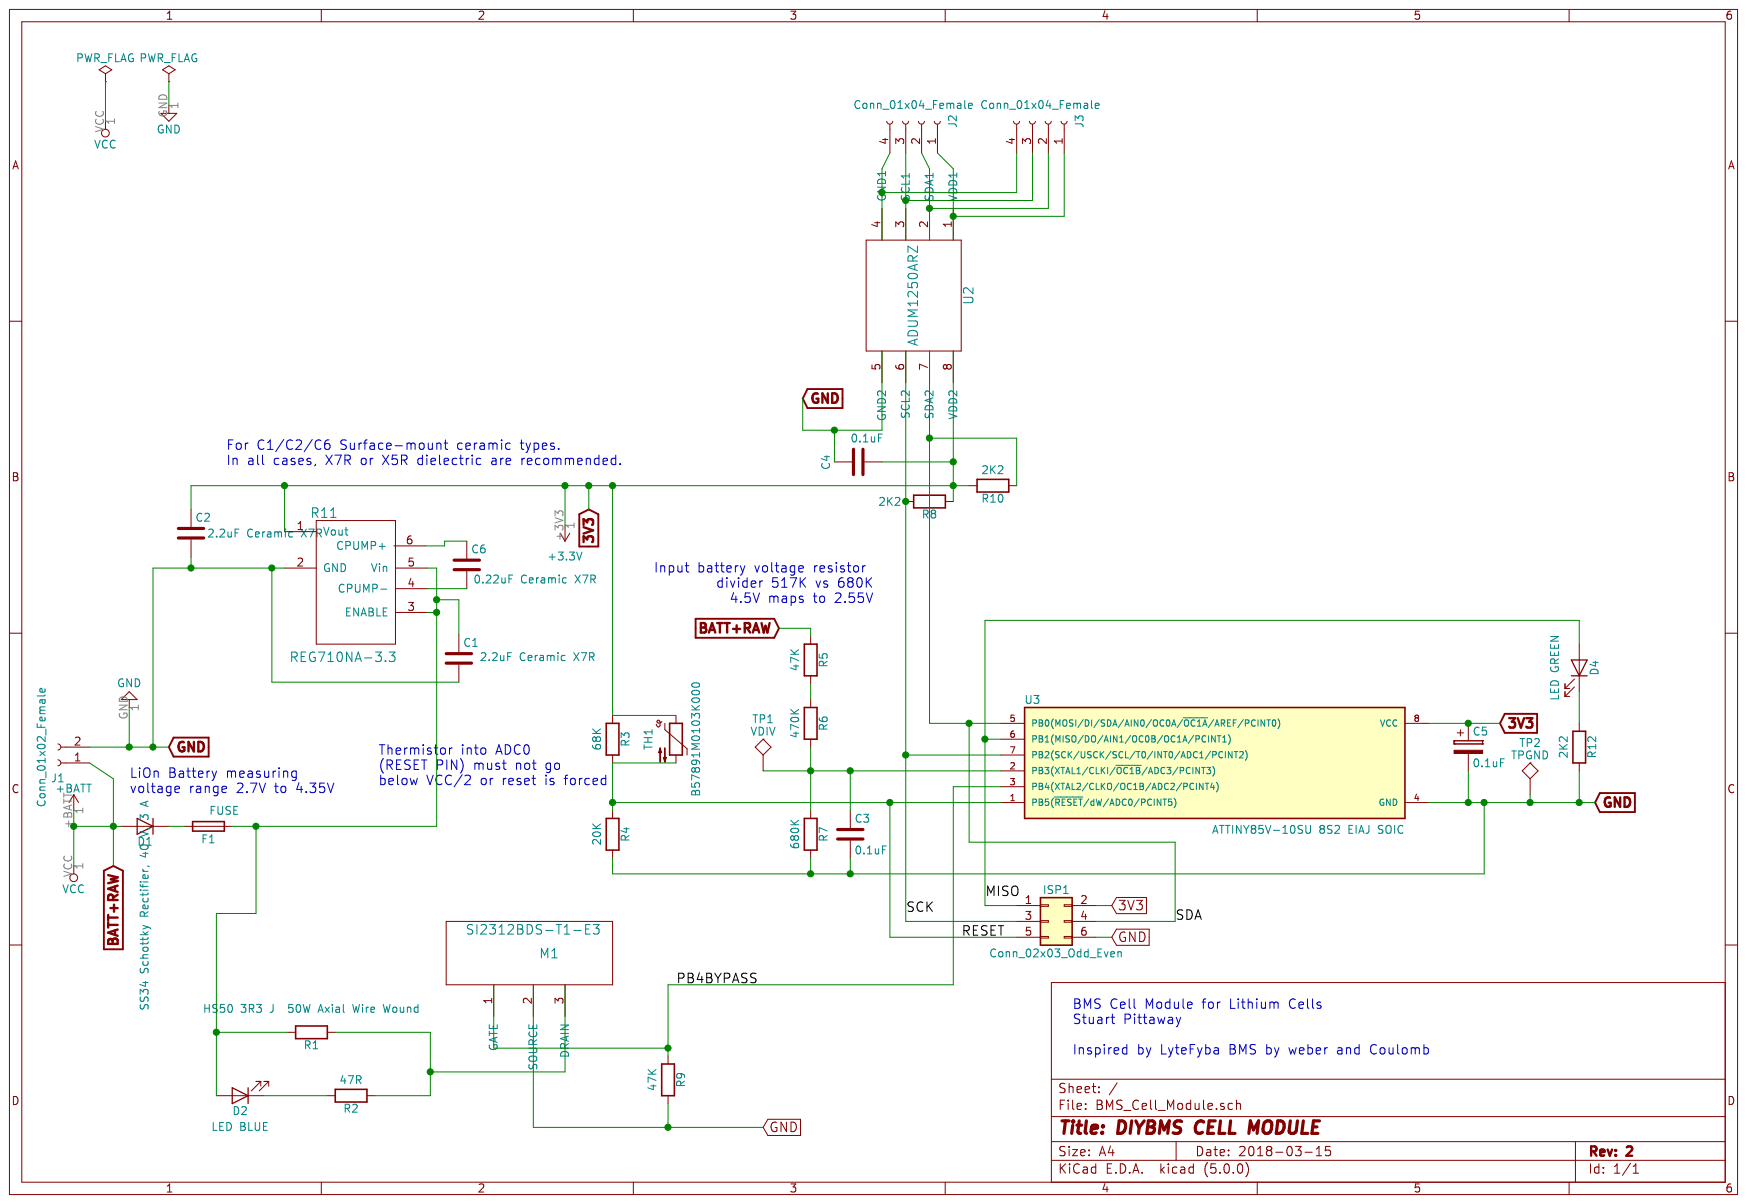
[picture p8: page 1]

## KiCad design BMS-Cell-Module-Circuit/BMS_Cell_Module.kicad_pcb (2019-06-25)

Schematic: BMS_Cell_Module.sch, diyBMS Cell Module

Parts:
C1, C2: 2.2uF; C_0805_2012Metric_Pad1.33x1.40mm_HandSolder
C3, C4: 0.1uF; C_0805_2012Metric_Pad1.33x1.40mm_HandSolder
C5: 0.1uF polarized; C_0805_2012Metric_Pad1.33x1.40mm_HandSolder
C6: 0.22uF; C_0805_2012Metric_Pad1.33x1.40mm_HandSolder
D1: SS34 Schottky 40V/3A; DO-221AC
D2: LED BLUE; LED_0805_2012Metric_Pad1.15x1.40mm_HandSolder
D4: LED GREEN; LED_0805_2012Metric_Pad1.15x1.40mm_HandSolder
F1: FUSE; R_1812_4532Metric_Pad1.42x3.40mm_HandSolder
ISP1: Conn_02x03_Odd_Even; Pin_Header_Straight_2x03_Pitch2.54mm
J1: Conn_01x02_Female; JST_PH_S2B-PH-K_02x2.00mm_Angled
J2, J3: Conn_01x04_Female; JST_PH_S4B-PH-K_04x2.00mm_Angled
Q1: SI2312BDS-T1-E3; SOT-23
R1: 2R/10W; R_Axial_Power_L50.0mm_W9.0mm_P60.96mm
R2, R8, R10, R12: 4K7; R_0805_2012Metric_Pad1.33x1.40mm_HandSolder
R3: 20K; R_0805_2012Metric_Pad1.33x1.40mm_HandSolder
R4: 10K; R_0805_2012Metric_Pad1.33x1.40mm_HandSolder
R6: 510K; R_0805_2012Metric_Pad1.33x1.40mm_HandSolder
R7: 680K; R_0805_2012Metric_Pad1.33x1.40mm_HandSolder
R9: 47K; R_0805_2012Metric_Pad1.33x1.40mm_HandSolder
TH1: B57891M0103K000; R_Axial_DIN0204_L3.6mm_D1.6mm_P2.54mm_Vertical
TP1: VDIV; TestPoint_Pad_D1.5mm
TP2: TPGND; TestPoint_Pad_D1.5mm
U1: REG710NA-3.3; SOT-23-6_Handsoldering
U2: ADUM1250ARZ; SOIC-8_3.9x4.9mm_P1.27mm
U3: ATTINY85V-10SU 8S2 EIAJ SOIC; SOIJ-8_5.3x5.3mm_P1.27mm

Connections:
3V3: C2.1, C4.1, C5.1, ISP1.2, R3.1, R8.2, R10.2, TH1.1, U1.1, U2.1, U3.8 (VCC)
/MISO: D4.2, ISP1.1, U3.6 (PB1)
/MOSI: ISP1.4, R8.1, U2.2, U3.5 (AREF/PB0)
/PB4BYPASS: Q1.1, R9.1, U3.3 (XTAL2/PB4)
/RST: ISP1.5, R3.2, R4.1, TH1.2, U3.1 (~RESET~/PB5)
/SCK: ISP1.3, R10.1, U2.3, U3.7 (PB2)
BATT+RAW: D1.2, J1.2, R6.1
GND: C1.2, C2.2, C3.2, C4.2, C5.2, ISP1.6, J1.1, Q1.2, R4.2, R7.2, R9.2, R12.2, TP2.1, U1.2, U2.4, U3.4 (GND)
unnamed: C1.1, D2.2, F1.1, R1.2, U1.3, U1.5
unnamed: C3.1, R6.2, R7.1, TP1.1, U3.2 (XTAL1/PB3)
unnamed: C6.1, U1.6
unnamed: C6.2, U1.4
unnamed: D1.1, F1.2
unnamed: D2.1, R2.2
unnamed: D4.1, R12.1
unnamed: J2.1, J3.1, U2.8
unnamed: J2.2, J3.2, U2.7
unnamed: J2.3, J3.3, U2.6
unnamed: J2.4, J3.4, U2.5
unnamed: Q1.3, R1.1, R2.1

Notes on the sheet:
Battery voltage divider 1.8→4.5V maps to ADC3=1.029V→2.571V
Li-Ion battery input 1.8→4.5V
C1/C2/C6 ceramic, X7R or X5R
2-channel bidirectional digital isolator for external I2C bus
side 1 strict I2C
side 2 relaxed I2C
Power resistor 10→50W
gate
source
drain
N-channel MOSFET

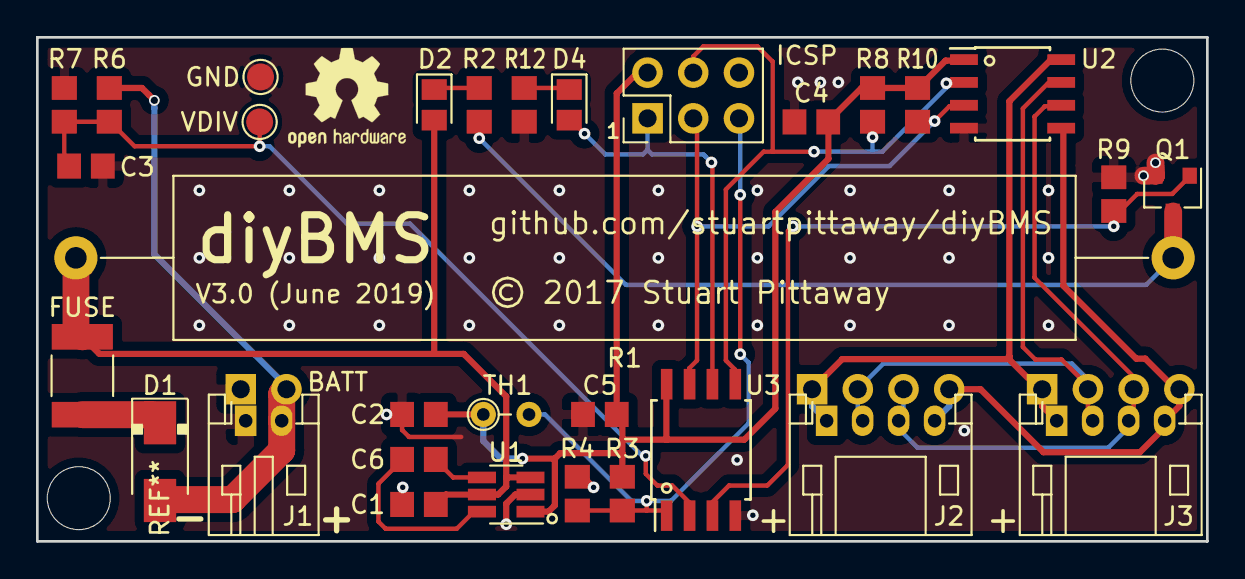
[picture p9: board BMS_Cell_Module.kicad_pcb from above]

Board: 2 copper layers, 65.0 x 28.0 mm, 31 parts (0 on the bottom side), 20 nets.

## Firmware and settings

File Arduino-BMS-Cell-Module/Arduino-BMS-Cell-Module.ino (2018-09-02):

/*
   ____  ____  _  _  ____  __  __  ___
  (  _ \(_  _)( \/ )(  _ \(  \/  )/ __)
   )(_) )_)(_  \  /  ) _ < )    ( \__ \
  (____/(____) (__) (____/(_/\/\_)(___/

  (c) 2017/2018 Stuart Pittaway

  This is the code for the cell module (one is needed for each series cell in a modular battery array (pack))

  This code runs on ATTINY85 processors and compiles with Arduino 1.8.5 environment

  You will need a seperate programmer to program the ATTINY chips - another Arduino can be used

  Settings ATTINY85, 8MHZ INTERNAL CLOCK, LTO enabled, BOD disabled, Timer1=CPU


  Use this board manager for ATTINY85
  http://drazzy.com/package_drazzy.com_index.json
  not this one https://raw.githubusercontent.com/damellis/attiny/ide-1.6.x-boards-manager/package_damellis_attiny_index.json

  ATTINY85/V-10PU data sheet
  http://www.atmel.com/images/atmel-2586-avr-8-bit-microcontroller-attiny25-attiny45-attiny85_datasheet.pdf

  To manually configure ATTINY fuses use the command....
  .\bin\avrdude -p attiny85 -C etc\avrdude.conf -c avrisp -P COM5 -b 19200 -B2 -e -Uefuse:w:0xff:m -Uhfuse:w:0xdf:m -Ulfuse:w:0xe2:m
  If you burn incorrect fuses to ATTINY85 you may need to connect a crystal over the pins to make it work again!
*/


//Show error is not targetting ATTINY85
#if !(defined(__AVR_ATtiny85__))
#error Written for ATTINY85/V chip
#endif

#if !(F_CPU == 8000000)
#error Processor speed should be 8Mhz internal dont forget to burn the bootloader/fuses!
#endif

#include <USIWire.h>
#include <EEPROM.h>
#include <avr/sleep.h>
#include <avr/wdt.h>

// __DATE__

//LED light patterns
#define GREEN_LED_PATTERN_STANDARD 0
#define GREEN_LED_PATTERN_BYPASS B01101100
#define GREEN_LED_PANIC B01010101
#define GREEN_LED_PATTERN_UNCONFIGURED B11101111

//Where in EEPROM do we store the configuration
#define EEPROM_CHECKSUM_ADDRESS 0
#define EEPROM_CONFIG_ADDRESS 20

#define MIN_BYPASS_VOLTAGE 3000U
#define MAX_BYPASS_VOLTAGE 4200U

//Number of TIMER1 cycles between voltage reading checks (240 = approx 30 seconds)
#define BYPASS_COUNTER_MAX 240

//Default i2c SLAVE address (used for auto provision of address)
#define DEFAULT_SLAVE_ADDR 21

//Configured cell modules use i2c addresses 24 to 48 (24S)
#define DEFAULT_SLAVE_ADDR_START_RANGE 24
#define DEFAULT_SLAVE_ADDR_END_RANGE DEFAULT_SLAVE_ADDR_START_RANGE + 24

//Number of times we sample and average the ADC for voltage
#define OVERSAMPLE_LOOP 16

//If we receive a cmdByte with BIT 6 set its a command byte so there is another byte waiting for us to process
#define COMMAND_BIT 6

#define COMMAND_green_led_pattern   1
//unused #define COMMAND_led_off   2
#define COMMAND_factory_default 3
#define COMMAND_set_slave_address 4
#define COMMAND_green_led_default 5
#define COMMAND_set_voltage_calibration 6
#define COMMAND_set_temperature_calibration 7
#define COMMAND_set_bypass_voltage 8
#define COMMAND_set_load_resistance 9


#define read_voltage 10
#define read_temperature 11
#define read_voltage_calibration 12
#define read_temperature_calibration 13
#define read_raw_voltage 14
#define read_error_counter 15
#define read_bypass_enabled_state 16
#define read_bypass_voltage_measurement 17
#define read_load_resistance 18

volatile bool skipNextADC = false;
volatile uint8_t green_pattern = GREEN_LED_PATTERN_STANDARD;
volatile uint16_t analogVal[OVERSAMPLE_LOOP];
volatile uint16_t temperature_probe = 0;
volatile uint8_t analogValIndex;
volatile uint8_t buffer_ready = 0;
volatile uint8_t reading_count = 0;
volatile uint8_t cmdByte = 0;

volatile uint8_t last_i2c_request = 255;
volatile uint16_t VCCMillivolts = 0;
volatile uint16_t ByPassVCCMillivolts = 0;
volatile uint16_t last_raw_adc = 0;
volatile uint16_t targetByPassVoltage = 0;
volatile uint8_t ByPassCounter = 0;
volatile boolean ByPassEnabled = false;
volatile boolean flash_green = false;

uint16_t error_counter = 0;

bool flashLed;

//Number of voltage readings to take before we take a temperature reading
#define TEMP_READING_LOOP_FREQ 16

//Default values
struct cell_module_config {
  // 7 bit slave I2C address
  uint8_t SLAVE_ADDR = DEFAULT_SLAVE_ADDR;
  // Calibration factor for voltage readings
  float VCCCalibration = 4.430;
  // Calibration factor for temp readings
  float TemperatureCalibration = 1.080;
  // Resistance of bypass load
  float LoadResistance = 10.0;
};

static cell_module_config myConfig;

void setup() {
  //Must be first line of setup()
  MCUSR &= ~(1 << WDRF); // reset status flag
  wdt_disable();

  //Pins PB0 (SDA) and PB2 (SCLOCK) are for the i2c comms with master
  //PINS https://github.com/SpenceKonde/ATTinyCore/blob/master/avr/extras/ATtiny_x5.md

  //pinMode(A3, INPUT);  //A3 pin 3 (PB3)
  //pinMode(A0, INPUT);  //reset pin A0 pin 5 (PB5)

  /*
    DDRB &= ~(1 << DDB3);
    PORTB &= ~(1 << PB3);

    DDRB &= ~(1 << DDB5);
    PORTB &= ~(1 << PB5);
  */

  pinMode(PB4, OUTPUT); //PB4 = PIN 3
  digitalWrite(PB4, LOW);

  ledGreen();
  delay(500);
  ledOff();

  //Load our EEPROM configuration
  if (!LoadConfigFromEEPROM()) {
    //Do something here for bad configuration??
  }

  cli();//stop interrupts

  analogValIndex = 0;

  initTimer1();
  initADC();

  // WDTCSR configuration:     WDIE = 1: Interrupt Enable     WDE = 1 :Reset Enable
  // Enter Watchdog Configuration mode:
  WDTCR |= (1 << WDCE) | (1 << WDE);

  // Set Watchdog settings - 4000ms timeout
  WDTCR = (1 << WDIE) | (1 << WDE) | (1 << WDP3) | (0 << WDP2) | (0 << WDP1) | (0 << WDP0);

  // Enable Global Interrupts
  sei();

  LEDReset();
  wait_for_buffer_ready();
  LEDReset();

  init_i2c();
}

boolean inPanicMode = false;

void panic() {
  green_pattern = GREEN_LED_PANIC;
  inPanicMode = true;
}

uint8_t previousLedState = 0;
void loop() {
  wdt_reset();

  if (last_i2c_request > 0) {
    //Count down loop for requests to see if i2c bus hangs or controller stops talking
    last_i2c_request--;
  }

  //If we are on the default SLAVE address then use different LED pattern to indicate this
  if (myConfig.SLAVE_ADDR == DEFAULT_SLAVE_ADDR) {
    green_pattern = GREEN_LED_PATTERN_UNCONFIGURED;
  } else {
    //We have had at least one i2c request and not currently in PANIC mode
    if (last_i2c_request == 0 && inPanicMode == false) {

      previousLedState = green_pattern ;

      //Panic after a few seconds of not receiving i2c requests...
      panic();

      //Try resetting the i2c bus
      Wire.end();
      init_i2c();

      error_counter++;
    }

    if (last_i2c_request > 0 && inPanicMode == true) {
      //Just come back from a PANIC situation
      LEDReset();
      green_pattern = previousLedState;
      inPanicMode = false;
    }

  }

  //Dont make this very large or watchdog will reset
  delay(250);
}

uint32_t calculateCRC32(const uint8_t *data, size_t length)
{
  uint32_t crc = 0xffffffff;
  while (length--) {
    uint8_t c = *data++;
    for (uint32_t i = 0x80; i > 0; i >>= 1) {
      bool bit = crc & 0x80000000;
      if (c & i) {
        bit = !bit;
      }
      crc <<= 1;
      if (bit) {
        crc ^= 0x04c11db7;
      }
    }
  }
  return crc;
}

void WriteConfigToEEPROM() {
  EEPROM.put(EEPROM_CONFIG_ADDRESS, myConfig);
  EEPROM.put(EEPROM_CHECKSUM_ADDRESS, calculateCRC32((uint8_t*)&myConfig, sizeof(cell_module_config)));
}

bool LoadConfigFromEEPROM() {
  cell_module_config restoredConfig;
  uint32_t existingChecksum;

  EEPROM.get(EEPROM_CONFIG_ADDRESS, restoredConfig);
  EEPROM.get(EEPROM_CHECKSUM_ADDRESS, existingChecksum);

  // Calculate the checksum of an entire buffer at once.
  uint32_t checksum = calculateCRC32((uint8_t*)&restoredConfig, sizeof(cell_module_config));

  if (checksum == existingChecksum) {
    //Clone the config into our global variable and return all OK
    memcpy(&myConfig, &restoredConfig, sizeof(cell_module_config));
    return true;
  }

  //Config is not configured or gone bad, return FALSE
  return false;
}

void init_i2c() {
  Wire.begin(myConfig.SLAVE_ADDR);
  Wire.onRequest(requestEvent);
  Wire.onReceive(receiveEvent);
}

void LEDReset() {
  green_pattern = GREEN_LED_PATTERN_STANDARD;
}

void factory_default() {
  EEPROM.put(EEPROM_CHECKSUM_ADDRESS, 0);
}

void Reboot() {
  TCCR1 = 0;
  TIMSK |= (1 << OCIE1A); //Disable timer1

  //Now power down loop until the watchdog timer kicks a reset
  ledGreen();

  /*
    set_sleep_mode(SLEEP_MODE_PWR_DOWN);
    adc_disable();
    sleep_enable();
    sleep_cpu();
  */
  //Infinity
  while (1) {}
}

void wait_for_buffer_ready() {
  //Just delay here so the buffers are all ready before we service i2c
  while (!buffer_ready) {
    delay(100);
    wdt_reset();
  }
}


void sendUnsignedInt(uint16_t number) {
  Wire.write((byte)((number >> 8) & 0xFF));
  Wire.write((byte)(number & 0xFF));
}

void sendByte(uint8_t number) {
  Wire.write(number);
}


union {
  float val;
  uint8_t b[4];
} float_to_bytes;

void sendFloat(float number) {
  float_to_bytes.val = number;

  Wire.write(float_to_bytes.b[0]);
  Wire.write(float_to_bytes.b[1]);
  Wire.write(float_to_bytes.b[2]);
  Wire.write(float_to_bytes.b[3]);
}

float readFloat() {
  float_to_bytes.b[0] = Wire.read();
  float_to_bytes.b[1] = Wire.read();
  float_to_bytes.b[2] = Wire.read();
  float_to_bytes.b[3] = Wire.read();

  return float_to_bytes.val;
}

void bypass_off() {
  targetByPassVoltage = 0;
  ByPassCounter = 0;
  ByPassEnabled = false;
  green_pattern = GREEN_LED_PATTERN_STANDARD;
}

union {
  uint16_t val;
  uint8_t b[2];
} uint16_t_to_bytes;

uint16_t readUINT16() {
  uint16_t_to_bytes.b[0] = Wire.read();
  uint16_t_to_bytes.b[1] = Wire.read();
  return uint16_t_to_bytes.val;
}

// function that executes whenever data is received from master
void receiveEvent(int howMany) {
  if (howMany <= 0) return;

  //If cmdByte is not zero then something went wrong in the i2c comms,
  //master failed to request any data after command
  if (cmdByte != 0) error_counter++;

  flashLed = true;

  cmdByte = Wire.read();
  howMany--;

  //Is it a command byte (there are other bytes to process) or not?
  if (bitRead(cmdByte, COMMAND_BIT)) {

    bitClear(cmdByte, COMMAND_BIT);

    switch (cmdByte) {
      case COMMAND_green_led_pattern:
        if (howMany == 1) {
          green_pattern = Wire.read();
        }
        break;

      case COMMAND_green_led_default:
        green_pattern = GREEN_LED_PATTERN_STANDARD;
        break;

      case COMMAND_factory_default:
        factory_default();
        Reboot();
        break;

      case COMMAND_set_voltage_calibration:
        if (howMany == sizeof(float)) {
          float newValue = readFloat();
          //Only accept if its different
          if (newValue != myConfig.VCCCalibration) {
            myConfig.VCCCalibration = newValue;
            WriteConfigToEEPROM();
          }
        }
        break;

      case COMMAND_set_temperature_calibration:
        if (howMany == sizeof(float)) {
          float newValue = readFloat();
          //Only accept if its different
          if (newValue != myConfig.TemperatureCalibration) {
            myConfig.TemperatureCalibration = newValue;
            WriteConfigToEEPROM();
          }
        }
        break;

      case COMMAND_set_load_resistance:
        if (howMany == sizeof(float)) {
          float newValue = readFloat();
          //Only accept if its different
          if (newValue != myConfig.LoadResistance) {
            myConfig.LoadResistance = newValue;
            WriteConfigToEEPROM();
          }
        }
        break;

      case COMMAND_set_bypass_voltage:
        if (howMany == sizeof(uint16_t)) {
          uint16_t newValue = readUINT16();
          //Only accept if its a realistic value and the value is LESS than the last voltage reading
          if (newValue >= MIN_BYPASS_VOLTAGE && newValue <= MAX_BYPASS_VOLTAGE && newValue < VCCMillivolts) {
            //TODO: Are we sure we really need all these variables??
            targetByPassVoltage = newValue;
            ByPassVCCMillivolts = VCCMillivolts;
            ByPassCounter = BYPASS_COUNTER_MAX;
            green_pattern = GREEN_LED_PATTERN_BYPASS;
            ByPassEnabled = true;
          } else {
            //Disable
            bypass_off();
          }
        }
        break;


      case COMMAND_set_slave_address:
        //Set i2c slave address and write to EEPROM, then reboot
        if (howMany == 1 ) {
          uint8_t newAddress = Wire.read();
          //Only accept if its a different address
          if (newAddress != myConfig.SLAVE_ADDR && newAddress >= DEFAULT_SLAVE_ADDR_START_RANGE && newAddress <= DEFAULT_SLAVE_ADDR_END_RANGE) {
            myConfig.SLAVE_ADDR = newAddress;
            WriteConfigToEEPROM();
            Reboot();
          }
        }
        break;

    }

    cmdByte = 0;
  } else {
    //Its a READ request

    switch (cmdByte) {
      case read_voltage:
        VCCMillivolts = Update_VCCMillivolts();
        flash_green = true;
        break;
    }
  }

  // clear rx buffer
  while (Wire.available()) Wire.read();
}


float Update_VCCMillivolts() {
  //Oversampling and take average of ADC samples use an unsigned integer or the bit shifting goes wonky
  uint32_t extraBits = 0;
  for (int k = 0; k < OVERSAMPLE_LOOP; k++) {
    extraBits = extraBits + analogVal[k];
  }
  //Shift the bits to match OVERSAMPLE_LOOP size (buffer size of 8=3 shifts, 16=4 shifts)
  uint16_t raw = (extraBits >> 4);

  //TODO: Get rid of the need for float variables....
  return (int)((float)raw * myConfig.VCCCalibration);
}

// function that executes whenever data is requested by master (this answers requestFrom command)
void requestEvent() {
  switch (cmdByte) {
    case read_voltage:
      //If we are in bypass then only return the voltage
      //thats taken outside of the resistor load being switched on
      if (ByPassEnabled) {
        sendUnsignedInt(ByPassVCCMillivolts);
      } else {
        sendUnsignedInt(VCCMillivolts);
      }

      break;

    case read_raw_voltage:
      sendUnsignedInt(last_raw_adc);
      break;

    case read_error_counter:
      sendUnsignedInt(error_counter);
      break;

    case read_bypass_voltage_measurement:
      sendUnsignedInt(ByPassVCCMillivolts);
      break;

    case read_bypass_enabled_state:
      sendByte(ByPassEnabled);
      break;

    case read_temperature:
      sendUnsignedInt((uint16_t)((float)temperature_probe * myConfig.TemperatureCalibration));
      break;

    case read_voltage_calibration:
      sendFloat(myConfig.VCCCalibration);
      break;

    case read_temperature_calibration:
      sendFloat(myConfig.TemperatureCalibration);
      break;

    case read_load_resistance:
      sendFloat(myConfig.LoadResistance);
      break;

    default:
      //Dont do anything - timeout
      break;
  }

  //Clear cmdByte
  cmdByte = 0;

  //Reset when we last processed a request, if this times out master has stopped communicating with module
  last_i2c_request = 150;
}

inline void ledGreen() {
  DDRB |= (1 << DDB1);
  PORTB |=  (1 << PB1);
}

/*
  inline void ledRed() {
  DDRB |= (1 << DDB1);
  PORTB &= ~(1 << PB1);
  }
*/
inline void ledOff() {
  //Low
  DDRB |= (1 << DDB1);
  PORTB &= ~(1 << PB1);
  /*
    //PB1 as input
    DDRB &= ~(1 << DDB1);
    //PB1 pull up OFF
    PORTB &= ~(1 << PB1);
  */
}

ISR(TIMER1_COMPA_vect)
{
  //Flash LED in sync with bit pattern


  if (green_pattern == 0) {
    if (flash_green)  {
      ledGreen();
    }
    flash_green = false;
  } else {
    ///Rotate pattern
    green_pattern = (byte)(green_pattern << 1) | (green_pattern >> 7);

    if (green_pattern & 0x01) {
      ledGreen();
    } else {
      ledOff();
    }
  }

  if (ByPassEnabled) {

    //TODO: We need to add in code here to check we don't overheat

    //This must go above the following "if (ByPassCounter > 0)" statement...
    if (ByPassCounter == 0 && analogValIndex == 0) {
      //We are in bypass and just finished an in-cycle voltage measurement
      ByPassVCCMillivolts = Update_VCCMillivolts();

      if (targetByPassVoltage >= ByPassVCCMillivolts) {
        //We reached the goal
        bypass_off();
      } else {
        //Try again
        ByPassCounter = BYPASS_COUNTER_MAX;
      }
    }

    if (ByPassCounter > 0)
    {
      //We are in ACTIVE BYPASS mode - the RESISTOR will be ACTIVE + BURNING ENERGY
      ByPassCounter--;
      digitalWrite(PB4, HIGH);

      if (ByPassCounter == 0)
      {
        //We have just finished this timed ACTIVE BYPASS mode, disable resistor
        //and measure resting voltage now before possible re-enable.
        digitalWrite(PB4, LOW);

        //Reset voltage ADC buffer
        analogValIndex = 0;
      }
    }

  } else {
    //Safety check we ensure bypass is always off if not enabled
    digitalWrite(PB4, LOW);
  }

  if (green_pattern == 0) {
    ledOff();
  }


  //trigger ADC reading
  ADCSRA |= (1 << ADSC);
}

ISR(ADC_vect) {
  // Interrupt service routine for the ADC completion
  //uint8_t adcl = ADCL;
  //uint16_t value = ADCH << 8 | adcl;

  uint16_t value = ADCW;

  //If we skip this ADC reading, quit ISR here
  if (skipNextADC) {
    skipNextADC = false;
    return;
  }

  if (reading_count == TEMP_READING_LOOP_FREQ ) {
    //Use A0 (RESET PIN) to act as an analogue input
    //note that we cannot take the pin below 1.4V or the CPU resets
    reading_count = 0;

    //We reduce the value by 512 as we have a DC offset we need to remove
    temperature_probe = value;

    //use ADC3 for input for next reading (voltage)
    ADMUX = B10010011;

    //Set skipNextADC to delay the next TIMER1 call to ADC reading to allow the ADC to settle after changing MUX
    skipNextADC = true;

  } else {

    //Populate the rolling buffer with values from the ADC
    last_raw_adc = value;
    analogVal[analogValIndex] = value;

    analogValIndex++;

    if (analogValIndex == OVERSAMPLE_LOOP) {
      analogValIndex = 0;
      buffer_ready = 1;
    }

    reading_count++;

    if (reading_count == TEMP_READING_LOOP_FREQ) {
      //use ADC0 for temp probe input on next ADC loop

      ADMUX = B10010000;

      //Set skipNextADC to delay the next TIMER1 call to ADC reading to allow the ADC to settle after changing MUX
      skipNextADC = true;
    }
  }

}

void initADC()
{
  /* this function initialises the ADC

        ADC Prescaler Notes:
    --------------------

     ADC Prescaler needs to be set so that the ADC input frequency is between 50 - 200kHz.

           For more information, see table 17.5 "ADC Prescaler Selections" in
           chapter 17.13.2 "ADCSRA – ADC Control and Status Register A"
          (pages 140 and 141 on the complete ATtiny25/45/85 datasheet, Rev. 2586M–AVR–07/10)

           Valid prescaler values for various clock speeds

       Clock   Available prescaler values
           ---------------------------------------
             1 MHz   8 (125kHz), 16 (62.5kHz)
             4 MHz   32 (125kHz), 64 (62.5kHz)
             8 MHz   64 (125kHz), 128 (62.5kHz)
            16 MHz   128 (125kHz)


    ADPS2 ADPS1 ADPS0 Division Factor
    000 2
    001 2
    010 4
    011 8
    100 16
    101 32
    110 64
    111 128

  */

  //NOTE The device requries a supply voltage of 3V+ in order to generate 2.56V reference voltage.
  // http://openenergymonitor.blogspot.co.uk/2012/08/low-level-adc-control-admux.html

  //REFS1 REFS0 ADLAR REFS2 MUX3 MUX2 MUX1 MUX0
  //Internal 2.56V Voltage Reference without external bypass capacitor, disconnected from PB0 (AREF)
  //ADLAR =0 and PB3 (B0011) for INPUT (A3)
  //We have to set the registers directly because the ATTINYCORE appears broken for internal 2v56 register without bypass capacitor
  ADMUX = B10010011;

  /*
    ADMUX = (INTERNAL2V56_NO_CAP << 4) |
          (0 << ADLAR)  |     // dont left shift ADLAR
          (0 << MUX3)  |     // use ADC3 for input (PB4), MUX bit 3
          (0 << MUX2)  |     // use ADC3 for input (PB4), MUX bit 2
          (1 << MUX1)  |     // use ADC3 for input (PB4), MUX bit 1
          (1 << MUX0);       // use ADC3 for input (PB4), MUX bit 0
  */

  /*
    #if (F_CPU == 1000000)
    //Assume 1MHZ clock so prescaler to 8 (B011)
    ADCSRA =
      (1 << ADEN)  |     // Enable ADC
      (0 << ADPS2) |     // set prescaler bit 2
      (1 << ADPS1) |     // set prescaler bit 1
      (1 << ADPS0);      // set prescaler bit 0
    #endif
  */
  //#if (F_CPU == 8000000)
  //8MHZ clock so set prescaler to 64 (B110)
  ADCSRA =
    (1 << ADEN)  |     // Enable ADC
    (1 << ADPS2) |     // set prescaler bit 2
    (1 << ADPS1) |     // set prescaler bit 1
    (0 << ADPS0) |       // set prescaler bit 0
    (1 << ADIE);     //enable the ADC interrupt.
  //#endif
}

static inline void initTimer1(void)
{
  TCCR1 |= (1 << CTC1);  // clear timer on compare match
  TCCR1 |= (1 << CS13) | (1 << CS12) | (1 << CS11) | (1 << CS10); //clock prescaler 16384
  OCR1C = 64;  //About eighth of a second trigger Timer1  (there are 488 counts per second @ 8mhz)
  TIMSK |= (1 << OCIE1A); // enable compare match interrupt
}

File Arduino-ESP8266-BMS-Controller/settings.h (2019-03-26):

#include "Arduino.h"

#ifndef config_settings_H_
#define config_settings_H_


//Where in EEPROM do we store the configuration
#define EEPROM_storageSize 2048
#define EEPROM_WIFI_CHECKSUM_ADDRESS 0
#define EEPROM_WIFI_CONFIG_ADDRESS EEPROM_WIFI_CHECKSUM_ADDRESS+sizeof(uint32_t)

#define EEPROM_CHECKSUM_ADDRESS 512
#define EEPROM_CONFIG_ADDRESS EEPROM_CHECKSUM_ADDRESS+sizeof(uint32_t)

struct wifi_eeprom_settings {
  char wifi_ssid[32 + 1];
  char wifi_passphrase[63 + 1];
};

//We have allowed space for 2048-512 bytes of EEPROM for settings (1536 bytes)
struct eeprom_settings { 
  bool emoncms_enabled;
  uint8_t emoncms_node_offset;
  int emoncms_httpPort;
  char emoncms_host[64 + 1];
  char emoncms_apikey[32 + 1];
  char emoncms_url[64 + 1];
  bool influxdb_enabled;
  char influxdb_host[64 +1 ];
  int influxdb_httpPort;
  char influxdb_database[32 + 1];
  char influxdb_user[32 + 1];
  char influxdb_password[32 + 1];
  bool autobalance_enabled;
  bool invertermon_enabled;
  float max_voltage;
  float balance_voltage;
  float balance_dev;
};

extern wifi_eeprom_settings myConfig_WIFI;
extern eeprom_settings myConfig;

void WriteConfigToEEPROM();
bool LoadConfigFromEEPROM();
void WriteWIFIConfigToEEPROM();
bool LoadWIFIConfigFromEEPROM();
void FactoryResetSettings();

#endif

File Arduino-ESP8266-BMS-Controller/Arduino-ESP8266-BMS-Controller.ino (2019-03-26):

/* ____  ____  _  _  ____  __  __  ___
  (  _ \(_  _)( \/ )(  _ \(  \/  )/ __)
   )(_) )_)(_  \  /  ) _ < )    ( \__ \
  (____/(____) (__) (____/(_/\/\_)(___/

  (c) 2017/2018/2019 Stuart Pittaway

  Modifications for InfluxDB and additions made by Colin Hickey
  
  This is the code for the controller - it talks to the cell modules over isolated i2c bus

  This code runs on ESP-8266-12E (NODE MCU 1.0) and compiles with Arduino 1.8.5 environment

  Arduino settings
  NodeMCU 1.0 (ESP-8266-12E module), Flash 4M (3MSPIFF), CPU 80MHZ

  Setting up ESP-8266-12E (NODE MCU 1.0) on Arduino
  http://www.instructables.com/id/Programming-a-HTTP-Server-on-ESP-8266-12E/

  c:\Program Files (x86)\PuTTY\putty.exe -serial COM6 -sercfg 115200,8,n,1,N

  i2c CLOCK STRETCH
  https://github.com/esp8266/Arduino/issues/698
*/

extern "C"
{
#include "user_interface.h"
}

#define LED_ON digitalWrite(D4, LOW)
#define LED_OFF digitalWrite(D4, HIGH)

#include <ESP8266WiFi.h>
#include <WiFiClient.h>
#include <ESP8266HTTPClient.h>


#include "bms_values.h"
#include "i2c_cmds.h"
#include "settings.h"
#include "SoftAP.h"
#include "WebServiceSubmit.h"
#include <Wire.h>

const int sensorIn = A0;
int mVperAmp = 66; // use 100 for 20A Module and 66 for 30A Module
int ACS712shift = 22;
bool InverterMon = false;

double Voltage = 0;
double VRMS = 0;
double AmpsRMS = 0;


//Allow up to 24 modules
cell_module cell_array[24];
int cell_array_index = -1;
int cell_array_max = 0;
unsigned long next_submit;
bool runProvisioning;

extern bool manual_balance;
bool max_enabled = false;
// 0=No balancing 1=Manual balancing started 2=Auto Balancing enabled 3=Auto Balancing enabled and bypass happening 4=A module is over max voltage
int balance_status = 0;
  
//Configuration for thermistor conversion
//use the datasheet to get this data.
//https://www.instructables.com/id/NTC-Temperature-Sensor-With-Arduino/
float Vin=3.3;     // [V]        
float Rt=10000;    // Resistor t [ohm]
float R0=20000;    // value of rct in T0 [ohm]
float T1=273.15;   // [K] in datasheet 0º C
float T2=373.15;   // [K] in datasheet 100° C
float RT1=35563;   // [ohms]  resistence in T1
float RT2=549.4;     // [ohms]   resistence in T2
float beta=0.0;    // initial parameters [K]
float Rinf=0.0;    // initial parameters [ohm]   
float T0=298.15;   // use T0 in Kelvin [K]
float Vout=0.0;    // Vout in A0 
float Rout=0.0;    // Rout in A0
float TempK=0.0;   // variable output
float TempC=0.0;   // variable output

EmonCMS emoncms;
Influxdb influxdb;

os_timer_t myTimer;

float getVPP() {
  float result;
  
  int readValue;             //value read from the sensor
  int maxValue = 0;          // store max value here
  int minValue = 1024;          // store min value here

   uint32_t start_time = millis();
   while((millis()-start_time) < 1000) //sample for 1 Sec
   {
       readValue = analogRead(sensorIn-ACS712shift);

       // see if you have a new maxValue
       if (readValue > maxValue) 
       {
           /*record the maximum sensor value*/
           maxValue = readValue;
       }
       if (readValue < minValue) 
       {
           /*record the maximum sensor value*/
           minValue = readValue;
       }
   }
   //Serial.println(readValue);
   // Subtract min from max
   result = ((maxValue - minValue) * 5.0)/1024.0;
      
   return result;
 }

void avg_balance() {
  uint16_t avgint = 0;
  float avgintf = 0.0;
       
  if ((myConfig.autobalance_enabled == true) && (manual_balance == false)) {
    
    if (cell_array_max > 0) {
    //Work out the average 
    float avg = 0;
    for (int a = 0; a < cell_array_max; a++) {
      avgintf = cell_array[a].voltage/1000.0;
      avg += 1.0 * avgintf;
    }
    avg = avg / cell_array_max;

    avgint = avg;

    balance_status = 2;
    
    //Serial.println("Average cell voltage is currently : " + String(avg*1000));
    //Serial.println("Configured balance voltage : " + String(myConfig.balance_voltage*1000));

    if ( avg >= myConfig.balance_voltage )  {
      for ( int a = 0; a < cell_array_max; a++) {
        if (cell_array[a].voltage > avg*1000) {
          cell_array[a].balance_target = avg*1000;
          balance_status = 3;
        }
      } 
    }  else {
      for (int a = 0; a < cell_array_max; a++) {
        command_set_bypass_voltage(cell_array[a].address,0); }}
        } 
  } else  balance_status = 0;    
}

void print_module_details(struct  cell_module *module) {
  Serial.print("Mod: ");
  Serial.print(module->address);
  Serial.print(" V:");
  Serial.print(module->voltage);
  Serial.print(" VC:");
  Serial.print(module->voltage_calib);
  Serial.print(" T:");
  Serial.print(module->temperature);
  Serial.print(" TC:");
  Serial.print(module->temperature_calib);
  Serial.print(" R:");
  Serial.print(module->loadResistance);
  Serial.println("");
}

void check_module_quick(struct  cell_module *module) {
  module->voltage = cell_read_voltage(module->address);
  module->temperature = tempconvert(cell_read_board_temp(module->address));   
  module->bypass_status = cell_read_bypass_enabled_state(module->address);
 if (module->voltage >= 0 && module->voltage <= 5000) {
    if ( module->voltage > module->max_voltage || module->valid_values == false) {
      module->max_voltage = module->voltage;
    }
    if ( module->voltage < module->min_voltage || module->valid_values == false) {
      module->min_voltage = module->voltage;
    }
    module->valid_values = true;
  } else {
    module->valid_values = false;
  }
}

void check_module_full(struct  cell_module *module) {
  check_module_quick(module);
  module->voltage_calib = cell_read_voltage_calibration(module->address);
  module->temperature_calib = cell_read_temperature_calibration(module->address);
  module->loadResistance = cell_read_load_resistance(module->address);
}
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

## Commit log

2017-11-09 Initial cell monitoring circuit
    [BMS_Cell_Module.kicad_pcb, BMS_Cell_Module.sch]
2017-11-09 Started work on PCB
    DONT USE THIS PCB FOR PRODUCTION!
    [BMS_Cell_Module.kicad_pcb, BMS_Cell_Module.sch]
2017-11-12 Split board into two sections
    [BMS_Cell_Module.kicad_pcb, BMS_Cell_Module.sch]
2017-11-13 Split PCB into two halves
    [BMS_Cell_Module.kicad_pcb]
2017-11-13 All pins connected on PCB
    [BMS_Cell_Module.kicad_pcb, BMS_Cell_Module.sch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]
2017-11-13 PCB files
2017-11-14 Update fuse and power socket
    [BMS_Cell_Module.kicad_pcb, _saved_BMS_Cell_Module.sch]
2017-11-14 Added ground plane to pcb
    [BMS_Cell_Module.kicad_pcb, BMS_Cell_Module.sch, _saved_BMS_Cell_Module.sch]
2017-11-14 First Gerber files
    [BMS_Cell_Module-B.Cu.gbl, BMS_Cell_Module-Dwgs.User.gbr, BMS_Cell_Module-Eco1.User.gbr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]
2017-11-14 Remove obsolete files
    [BMS_Cell_Module-B.Cu.gbr, BMS_Cell_Module-Edge.Cuts.gbr, BMS_Cell_Module-F.Cu.gbr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]
2017-11-14 Remove files
    [BMS_Cell_Module.drl]
2017-11-16 Updated gerbers with bottom solder mask
    [BMS_Cell_Module-B.Cu.gbl, BMS_Cell_Module-B.Mask.gbs, BMS_Cell_Module-B.SilkS.gbo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]
2017-11-16 Project file changes
    [BMS_Cell_Module.kicad_pcb, BMS_Cell_Module.sch]
2017-11-18 Getting i2c to work properly
2017-11-19 Debugging ESP8266 crappy i2c issues
    Clock stretching appears to be breaking ESP8266 code
    [Arduino-BMS-Cell-Module.ino, Arduino-BMS-Controller-Test.ino]
2017-11-20 Working i2c using wire library
2017-11-20 Changed freq to 8Mhz to improve i2c handling
2017-11-20 Delay after changing MUX in ADC ISR
2017-11-22 Write configuration to EEPROM and trigger LED on TIMER1
2017-11-23 Implemented watchdog timeout and factory reset functions
    [Arduino-BMS-Cell-Module.ino, Arduino-BMS-Controller-Test.ino]
2017-11-23 Commands to retrieve calibration values
2017-11-25 Added set calibration values functions
2017-11-26 Removed RED led and improved test functions in temporary controller
2017-11-26 Remove red led code
2017-11-27 Initial code for resistor bypass/balancing
2017-11-29 Started redesign of PCB
    [BMS_Cell_Module.kicad_pcb, BMS_Cell_Module.sch]
2017-12-02 Start of new PCB layout for v2
    [BMS_Cell_Module-B.Cu.gbl, BMS_Cell_Module-B.Mask.gbs, BMS_Cell_Module-B.SilkS.gbo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]
2017-12-02 Custom PCB footprints
    [BMS_Cell_Module.sch]
2017-12-02 Updated PCB layout
    [BMS_Cell_Module.kicad_pcb, BMS_Cell_Module.sch]
2017-12-03 Revised PCB
    [BMS_Cell_Module.kicad_pcb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]
2017-12-03 New Gerbers
    [BMS_Cell_Module-B.Cu.gbl, BMS_Cell_Module-B.Mask.gbs, BMS_Cell_Module-B.SilkS.gbo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]
2017-12-03 Update BOM
2017-12-03 Update pictures
    [BMS_Cell_Module.kicad_pcb]
2017-12-08 Start of real DIY BMS controller
2017-12-11 Fixed CRC32 code not use the library!
    [settings.cpp]
2017-12-12 Post data into emoncms for cell module voltages and temperatures
2018-01-06 Minor tweaks
    [BMS_Cell_Module.kicad_pcb]
2018-01-06 Swap to google loader
    [SoftAP.cpp]
2018-01-08 Missing bracket
2018-01-15 Store min/max voltage over time
2018-01-15 Updated code for provision button
2018-01-23 Enable cell provisioning and calibration functions
2018-02-04 Change led pattern to light after comms and return correct voltage during bypass
    [Arduino-BMS-Cell-Module.ino]
2018-02-04 Fix flashing led issues
    [Arduino-BMS-Cell-Module.ino]
2018-02-06 Factory reset and resistance calibration
    [Arduino-ESP8266-BMS-Controller.ino, SoftAP.cpp, bms_values.h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]
2018-02-06 Web pages for new calibration options
2018-02-06 Configure resistance of bypass load
2018-02-07 Automatic temperature calibration sync
2018-02-07 Added voltage calibration function
2018-03-15 Minor amends
    [BMS_Cell_Module.kicad_pcb, BMS_Cell_Module.sch]
2018-03-15 Updated Gerbers
    [BMS_Cell_Module-B.Cu.gbl, BMS_Cell_Module-B.Mask.gbs, BMS_Cell_Module-B.Paste.gbp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]
2018-04-07 Wire.setClockStretchLimit
    Change Wire.setClockStretchLimit(1500); and order.
2018-04-08 check for invalid voltages.
2018-04-14 Update Bill Of Materials in README for readability.
    Grouped the capacitor and resistor values, ordering by their schematic name.
2018-07-22 Update R3 value in schematic to match pcb
    In #5 I had set R3 to 68K based on the schematic value, rather than the 20k value on the PCB. This fixes the discrepancy.
    [BMS_Cell_Module.sch]
2018-08-13 Inverter Monitoring
    This allows the connection of an ACS712 to pin A0 which allows you to monitor the current draw of an external inverter.
2018-09-02 Updated KICAD to version 5 (no circuit changes)
2018-09-02 Fix for issue #12
    [Arduino-ESP8266-BMS-Controller.ino, SoftAP.cpp]
2018-09-26 First check in
    [BMS_Cell_Module-B.Cu.gbl, BMS_Cell_Module-B.Mask.gbs, BMS_Cell_Module-B.Paste.gbp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]
2018-09-26 resistor values to 4.7K instead of 2.2K
    Working version, simplified some resistor values to 4.7K instead of 2.2K to reduce number of resistor types needed
2018-09-27 Updated images
    [BMS_Cell_Module.kicad_pcb]
2018-09-27 Change BOM
2018-09-27 Removed URLs for incorrect sized compontents
    [BMS_Cell_Module-B.Cu.gbl, BMS_Cell_Module-B.Mask.gbs, BMS_Cell_Module-B.SilkS.gbo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]
2018-12-04 Change resistor value to prevent reset during cold temp conditions
    Fix issue #16
    [BMS_Cell_Module.sch]
2018-12-04 Updated BOM
2019-04-01 Update BMS_Cell_Module_BOM.html
    Added sizes to resistors and caps to avoid confusion and added links for components to vendor websites.
2019-05-30 added digikey bom for easy parts ordering
    [BMS_Cell_Module_BOM_DigiKey.csv]
2019-06-25 Updated Gerber files after removal of R5
    [BMS_Cell_Module-B_Cu.gbl, BMS_Cell_Module-B_Mask.gbs, BMS_Cell_Module-B_SilkS.gbo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]
2019-06-25 Working Gerbers (June)
    [BMS_Cell_Module-B.Cu.gbl, BMS_Cell_Module-B.Mask.gbs, BMS_Cell_Module-B.SilkS.gbo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]

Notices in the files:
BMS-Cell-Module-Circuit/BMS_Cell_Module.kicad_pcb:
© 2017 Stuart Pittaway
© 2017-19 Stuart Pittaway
